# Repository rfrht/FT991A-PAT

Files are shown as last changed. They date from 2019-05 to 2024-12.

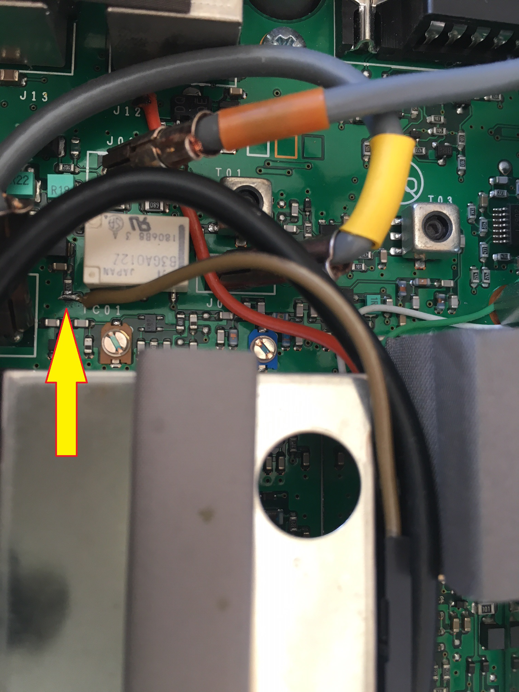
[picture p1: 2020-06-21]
Design/tx9.jpg

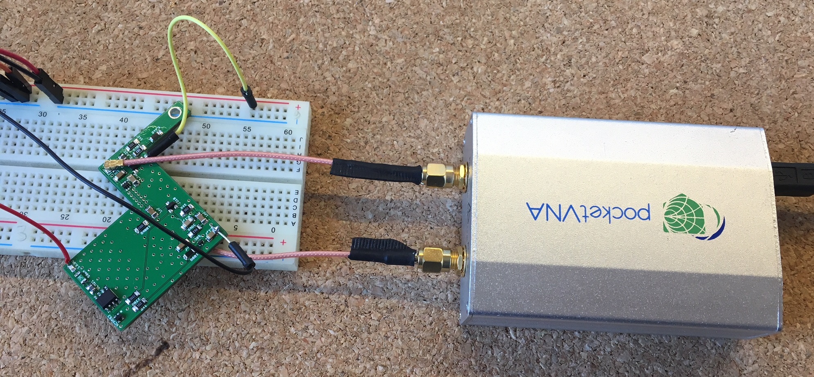
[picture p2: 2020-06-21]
Design/dut.jpg

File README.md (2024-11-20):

# Buffered IF tap board for Panadapter / SDR in a Yaesu FT-991-A

## Instructions, tests, pictures and full documentation: Check the [Wiki](https://github.com/rfrht/FT991A-PAT/wiki)

## Yaesu FT-991/A Custom Panoramic Adapter Buffered TAP Board for external SDR / Spectrum Analyser

This project is a remix of OE2DOR's [perfect and neatly crafted](https://raw.githubusercontent.com/Lightning1984/FT991A-PAT/PAT-Light/Design/FT991-PAT_Installed.jpg) FT-991/A Panadapter board with a high impedance IF tap, in order to disturb to a [minimum](https://youtu.be/yeTeMTJRBIg) the radio sensitivity.

This design is compatible with both A and non-A FT-991 transceivers.

The objective is to actually **lodge** a RTL-SDR **inside** a FT-991/A, with no extra cables coming off the radio.

The schematics are in Autodesk Eagle EDA format. Check the [Schematic](Schematic) folder. The [Design](Design) folder contains the ready to print Gerber files, images and some ancillary material.

The project genesis and some discussion are logged on QRZ Forum: [A FT-991/A IF tap for Panadapter / RTL-SDR inside the radio](https://forums.qrz.com/index.php?threads/hard-hack-embedding-a-sdr-in-ft-991a-need-rf-designers-review.650840/). If you need to ask questions, either file a Github Issue (preferred) or use the QRZ Forum.

If you are interested in build your own, [click here to download the Gerber](Design/board-gerbers.zip) and order in your favourite PCB Fab (like [JLCPCB](https://jlcpcb.com/quote), super cheap, good quality and $0 shipping on first order). **Ensure to read the [Wiki](https://github.com/rfrht/FT991A-PAT/wiki)**.

### Notes:

* The board (5 samples) costed $2 in [jlcpcb.com](https://jlcpcb.com/quote).
* The [parts](Design/bom-ft991-panadapter.csv) costs around $20 in Digi-Key.
* The IF signal is wide open, spanning the radio's [preselector filter range](/rfrht/FT991A-PAT/wiki/appendix-preselector-rx-stage-characteristics). With that comes also a problem: Very strong signals in passband might spew images through the spectrum in your SDR. Use the RTL-SDR RX gain to counteract.
* There's a Full Version with some extra bells and whistles (more details in the Wiki). Use the Branch "Rev-R-Full".

### Changelog:
Check [Here](CHANGELOG.md)

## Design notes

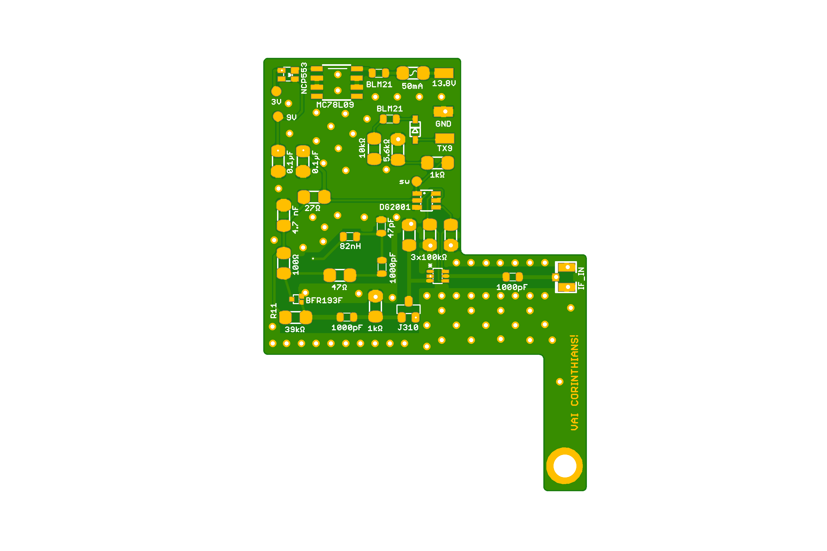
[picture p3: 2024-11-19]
Design/FT991-PAT_Bottom.png

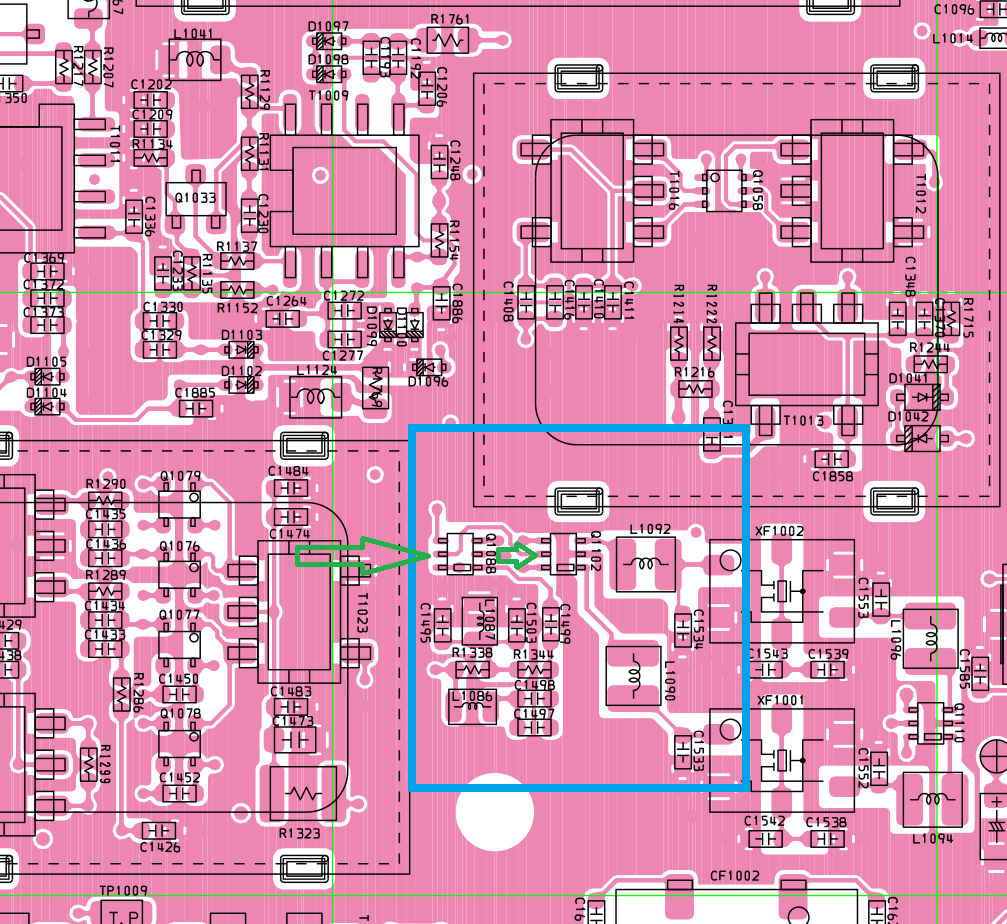
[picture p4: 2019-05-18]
Design/ft-991-tap-point.png

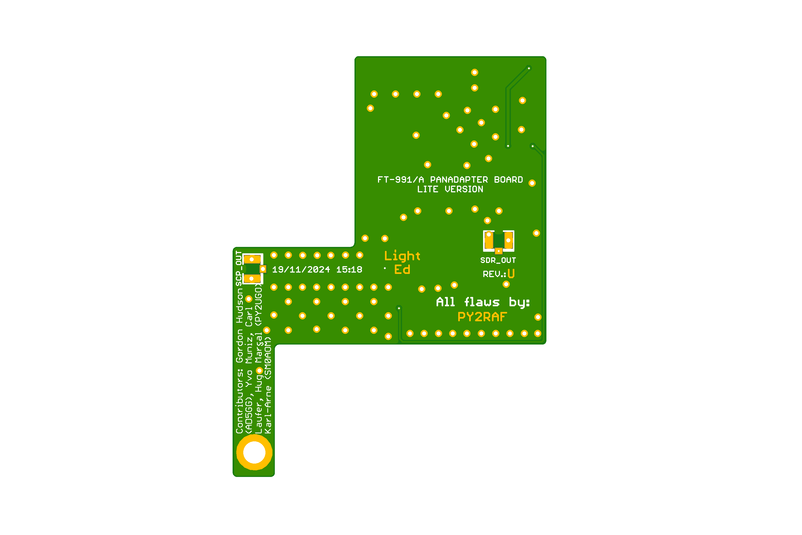
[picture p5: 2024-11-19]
Design/FT991-PAT_Top.png

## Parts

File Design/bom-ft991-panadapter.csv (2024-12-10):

Qty | Value | Parts | Digi-KeyPart
2 | 0.1µF | C2 C3 | 732-8109-1-ND
1 | 4700pF | C13 | 732-8119-1-ND
3 | 1000pF | C1 C11 C12 | 399-C0805C102J5GAC7800CT-ND
1 | 47pF | C14 | 712-QSCT251Q470G1GV001ECT-ND
3 | 100kR | R1 R5 R6 | CR1206-FX-1003ELFCT-ND
1 | 39kR | R11 | 118-CR1206-FX-3902ELFCT-ND
1 | 10kR | R3 | CR1206-FX-1002ELFCT-ND
1 | 5.6kR | R4 | 311-5.6KERCT-ND
2 | 1kR | R2 R7 | CR1206-FX-1001ELFCT-ND
1 | 100R | R12 | CR1206-FX-1000ELFCT-ND
1 | 47R | R13 | CR1206-FX-47R0ELFCT-ND
1 | 27R | R14 | CR1206-FX-27R0ELFCT-ND
1 | 82nH | L1 | 445-1034-1-ND
2 | BLM21 | L2 L3 | 541-2293-1-ND
1 | 50mA | F1 | 283-3132-1-ND
1 | 1SS355VM | D1 | 1SS355VMFHTE-17CT-ND
1 | PE4259 | Q1 | 1046-1011-1-ND
1 | MC78L09 | Q2 | MC78L09ABDR2GOSCT-ND
1 | DG2001 | Q3 | DG2001EDV-T1-GE3CT-ND
1 | NCP553 | Q5 | NCP553SQ30T1GOSCT-ND
1 | J310 | Q7 | MMBFJ310LT3GOSCT-ND
1 | BFR193F | Q8 | BFR193FH6327XTSA1CT-ND
3 | U.FL Port | X1 X2 X3 | A144746CT-ND
1 | U.FL IF Cable | J1 | WM9117-ND
1 | U.FL Panadapter to SDR Cable | J3 | 2057-CA-DKCA1-152L0-I0-12-ND
1 | USB2514BI | Q1012 | USB2514BI-AEZG-CT-ND

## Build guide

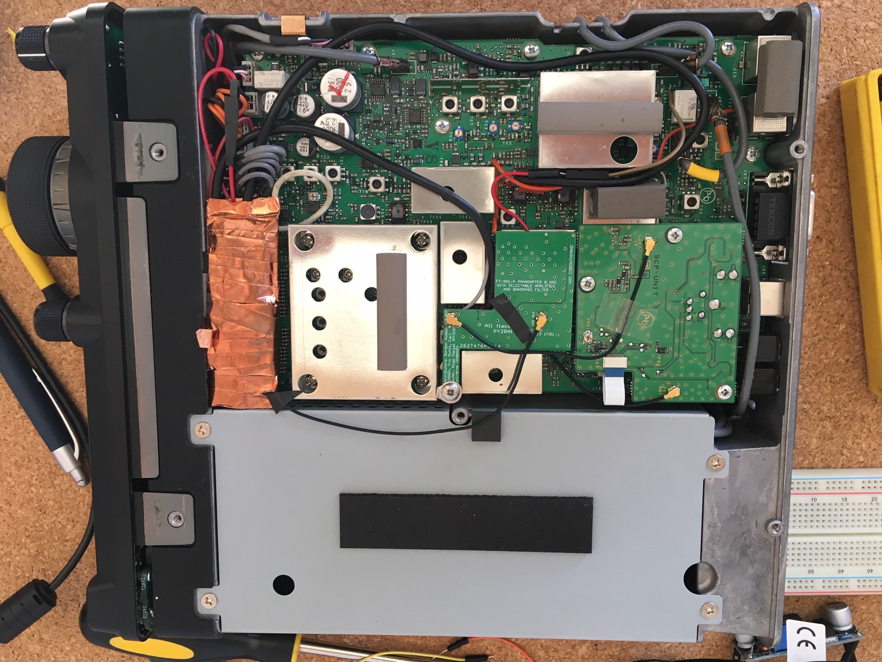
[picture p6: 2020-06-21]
Design/FT991-PAT_Installed.jpg

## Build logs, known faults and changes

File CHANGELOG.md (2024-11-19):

# Changelog

19/Nov/2024 - Revision U, Lite version
* Minor changes over Rev. T: Updated some component values, improved footprint for BFR193 (it's a **ROYAL PAIN IN THE ASS** to solder) and NCP553. Version is good enough to be promoted to Master branch.
* Resolves: [#20](https://github.com/rfrht/FT991A-PAT/issues/20), [#26](https://github.com/rfrht/FT991A-PAT/issues/26), [#27](https://github.com/rfrht/FT991A-PAT/issues/27)

28/May/2024 - Revision T, Lite version
* Fixed a gross flaw in Revision S: The RF switch was flipped out /o\  Resolves #25
* Updated BOM, renamed some capacitors and the matching network components are labeled as {C,R}1x
* There are more gain to be obtained from BFR193. Added a bias and matching network design from [Infineon's AN-1806](https://www.infineon.com/dgdl/Infineon-Design_Guide_for_low_noise_TR_in_FM_radio_FE-ApplicationNotes-v01_00-EN.pdf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). While the matching network isn't suitable for BFR193, the footprints will be good enough to test other components and values. Capacitors are 0805, Resistors are 1206.
* This revision is planned to be a testbed for a proper bias and match network in order to get better gain figures from BFR193.

11/Apr/2022 - Revision S, Full Version
* Replaced 2SC5086 with BFR193F amplifier, since 2SC5086 is now EOL
* Added a RF choke (L1) to avoid signal feedback propagating in 3V line
* New RF switch design - now uses an analog switch to flip the RF switch.
  While this added new parts (1 switch and two resistors) and extra
  complexity, this actuation format is industry-standard and allows
  for substitutes of PE4259 (which was unobtanium during the pandemics).

28/Jan/2022 - Revision R, Full & Lite
* Designed larger pads for the Diodes and NCP553

14/Apr/2021 - Revision R, Full & Lite
* Removed C6 - That's for DC blocking and no DC is present at this point
* Removed R6, R9 - J310 chain connected directly to +9V lines, 2SC5086 connected directly to 3V line.
* Cleared some lines away away from the PCB border, too close to PCB edge.

21/Feb/2021 - Revision Q, Full & Lite
* Better Silk-Screen Pin 1 markings for Power regulators
* Larger footprint for 2SC5086
* Moving 0.1µF transistor caps away from RF section
* Lots of re-routing
* Changing 1000 pF decoupling caps to _Low ESL_ type and 0805 footprint for better RF performance
* Took advantage of J310 [source & drain interchangeability](https://www.allaboutcircuits.com/textbook/semiconductors/chpt-5/transistor-switch-jfet/) and rerouted component for better placement and signal routing.
* Labeled a few signals in Eagle file for better understanding of signal route/path
* Changed two resistors in Amplifier stage for extra 0.3 dB gain - and updated BOM
* Added ground pad
* Larger ground exposed ground pad near at the screw
* Changed pad for RF components to a rounded layout
* Enlarged the RF wire signal, in order to reduce the internal signal impedance
* Improved component silk screen, for better component placement cue (and get rid of manual silk cues)
* Removed components from the board lid part, moved to larger board part

05/Jul/2020 - Revision P, Lite Version
* Repositioned the SDR Out port to right above the DC block cap
* Changed RF switch layout - now IF input uses the RF switch's `RFC` port instead of RF2 - The PE4259's `RF{N}` port gets in a grounded state instead of just reflecting out the data when the port is not selected/active. More details [here](https://github.com/rfrht/FT991A-PAT/wiki/appendix-pe4259-grounded-rf-port-when-port-is-not-selected)
* Got rid of the "Grounding" in RF1 port; that's not necessary because... Above
* Because of that... One less component (the 4.7 nF C2 cap)
* Few text corrections
* Added test pads for 9V, 3V and RF Switch
* A voltage line re-routed to the board edge, less ground plane disturbance

24/Nov/2019 - Lite Edition
* This revision features the bare minimum of the panadapter board: The TX signal RF switch and the Amplifier
* Greatly simplified and cheaper design
* More gain (due to less insertion loss of the RF switch chain that existed in previous revisions)

02/Nov/2019 - Revision O
* Board redesign
* Moved everything to the bottom side of the board, except for a RF switch and SDR/Scope unit ports
* Redesigned BPF (thanks to [SM0AOM](https://forums.qrz.com/index.php?threads/filter-design-help.671664/))
* Changed panadapter default state from disabled to enabled
* Changed RF front-end switch to use the TX9 signal instead of RX9
* Added a PTC fuse
* Choosed a simpler (and cheaper) 9V regulator

22/Jun/2019 - Revision N
* Removed the 5V regulator
* Removed the USB provisions
* Removed the G4HUP LPF. Reasoning: Found it of no use, since it cuts the signal 24 MHz above the IF center frequency. Replaced with a selectable 3-MHz wide 69.450 MHz BPF.
* Moved regulators to the top side of the board (to take advantage of heat dissipation)
* Moved the SDR Out port to the top of the board
* Added a large uncovered ground pad
* Tried to group the signals as much as possible and moved everything to the top of the board
* And thus, reduced significantly the BOM (35 to 25 different parts)

29/May/2019 - Revision M
EXPERIMENTAL.  In this revision:
* Got rid of the USB receptacle - Too much space in a tight radio
* Moved all GPIO pads to the upper board side
* Added a few missing Pin 1 references
* Renamed voltage regulators to somewhat shorter name
* Small re-routing - 9V regulator was entangled with capacitor

24/May/2019 - Revision L
EXPERIMENTAL.  In this revision:
* Added the ability to bypass entirely the amplifier and filters
  - Selectable by RF switch (default: off)
* Added a 3-pole Chebyshev Band-pass Filter centered at 69.450 MHz, 3 MHz
  wide
  - Selectable by RF switch (default: off)
* Revamped the Block Diagram
* Added the BPF LT-SPICE simulation
* Updated README, BOM, Gerbers and Pictures
* And yes, board is getting somewhat cluttered.

19/May/2019 - Revision K
* Changed footprints: BOM specifies 1206, project had 0805
  - Unified everything Resistors and Capacitors in 1206
  - Inductors are 0805
* A few routing enhancements
* Recalculated the component indexes
* Updated BOM to reflect the new component index
  - And also found a unaccounted resistor, whoops.
  - Reviewed the entire BOM and circuits. Now everything should be fine.

18/May/2019 - Revision J
* Changed SCPON signal to RX9
  - Added a Voltage Divider
* Changed the SMA-to-U.FL cable
* Added a few vias in large ground pads for voltage regulators
* Moved USB port a bit back in PCB

07/Apr/2019 - Revision I
* Created USB interconnection with the SDR
* Proper power management: Three voltage regulators in the board (9V, 5V, 3.3V)
* Power is only enabled with signaling coming from USB hub; otherwise, board quiesce
* Updated BOM

29/Mar/2019 - Revision H
* Revised routes in Cheb Filter - Made the tracks fatter and straighter
* Repositioned Q2 for better signal routing
* Better unit spelling in silk screen for resistors
* Flipped IF/SCP ports
* A few routing changes.

27/Mar/2019 - Revision G
* Removed a lingering DC blocker capacitor in filter in after RF switch.
* Added chokes in DC IN lines (3.3V and 5V) (yet another Gordon trick)

27/Mar/2019 - Revision F
* Added 1 nF capacitors in RF lines in PE4529 (except RF2, goes with a 470 pF to GND)
* Got rid of the VCC via which was crossing the RF line (argh)
* Finally got the courage to change a bit the board layout and escape from the thin strip that I was working previously.
* And another THANK YOU to Gordon AD5GG for his invaluable feedback

25/Mar/2019 - Revision E
* Changed the switch from a analog one (was a SN74LVC1G66) to a RF one (now: PE4259) (thanks to Gordon Hudson AD5GG)
* Now using 3.3V (because of PE4529)
* The switch default state now grounds the SDR
* Updated the list of contributors in PCB Silk Screen.

20/Mar/2019 - Revision D
* Moved to [OE2DOR](https://github.com/Lightning1984) **amazing** board design
* Added provision for two external inputs for latching control (actuating on a RF switch), isolating the SDR receiver when the two inputs are not in HIGH state. This is a bit of overkill in FT-991/A, but I want to be able to control the IF tap by software and be able to unplug it completely when not in use, without having to open the radio ;-)

### History (OE2DOR)

05/11/2018
 - Board Layout changed to fit neatly inside FT-991/A
 - Connection to IF using existing U.FL jumper cable 
 - Connection to FT991A SCP-UNIT using additional short U.FL jumper cable
 - Connection to SDR/SpectrumAnalyser using new U.FL to SMA cable
 - Mounting using M3/10mm PCB Spacer soldered to head of existing PCB mounting screw (since PCB mounting screw has no metric thread)
 - Fixation using M3 Plastic nut & screw sticking into tuning hole of shielding box
 - All but one resitor (1206) changed to 0805 to allow for smaller PCB layout

History (G4HUP/W3AXL)
Updated G4HUP / W3AXL panadapter tap
Simple revision to the G4HUP high-impedance IF tap with specific components and updated filters.

12/14/2017
 - Revised parts.md to add quantity of parts needed.

12/10/2017
 - Up and running on a Yaesu FT-991/A

12/10/2017
 - Revised component values to values that you can actually obtain. Added digikey parts list.

10/22/2017
 - Second revision testing complete and satisfactory. Up and running on a Yaesu FT-450D

08/30/2017
 - Schematic revised to fix capacitor placement error in original schematic. New boards sent out for fabrication and testing will be done when they get back.

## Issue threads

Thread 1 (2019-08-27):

Band-Pass Filter does not work.

rfrht, 2019-08-27:
**ISSUE**
As per [testing](https://github.com/rfrht/FT991A-PAT/wiki/testing) in Revision N, the selectable band-pass filter does not work - Matter of fact, it kills entirely the signal, from 1-900 MHz.

**ENVIRONMENT**
Revision N.

**RESOLUTION**
As of now this is not of super big concern, because the BPF is turned off by default.

Two possible resolutions;

1. Removing it entirely;
2. Implementing a good design.

rfrht, 2019-09-01:
Post at https://forums.qrz.com/index.php?threads/filter-design-help.671664/

rfrht, 2019-10-07:
Golden in aea2828dc01a8a442936111a30bc96a85ca1b191

_in vitro_ results in [QRZ Thread](https://forums.qrz.com/index.php?threads/filter-design-help.671664/page-2#post-5182107)

Pending build and verify _in vivo_.

rfrht, 2020-06-21:
Resolved@ Thanks to SM4AOM/Karl Arne.

Closed 2020-06-21.

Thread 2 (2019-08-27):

Remove the "Panadapter Enable"

rfrht, 2019-08-27:
**ISSUE**
The board only comes to life with a `PAT_ENABLE` signal. This requires a Voltage regulator with a Enable signal and extra wiring on the radio.

**BACKGROUND**
Originally, the project intended to also power the SDR dongle. However, I found that when feeding the SDR through the Panadapter board, the 9V regulator [gets real hot](https://forums.qrz.com/index.php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).
The radio is designed to run cold, as hot environment adds more noise to the sensible transistors/amplifiers in the RX stage. At this point, a selectable "Enable" made sense.
However, starting with Revision N, the SDR is powered by the +5V bus on the radio, straight from a 1.5A LDO which is properly attached to the aluminum chassis for proper heat dissipation.

**ENVIRONMENT**
All Revisions through N.

**RESOLUTION**
Use a smaller and cheaper 9V LDO.

As a workaround, wire directly the 13.8 `Vin` to the `PAT_ENABLE` pad.

rfrht, 2019-09-01:
Assigned, WIP.

rfrht, 2019-10-07:
Fixed in aea2828dc01a8a442936111a30bc96a85ca1b191

Closed 2019-10-07.

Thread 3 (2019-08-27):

Change first RF switch to "On by Default"

rfrht, 2019-08-27:
**ISSUE**
Currently, the panadapter does not tap the signal by default - It only opens to the signal upon the presence of both `RX_EN` **and** `RX_9` signals. Enabling a GPIO line to open the panadapter is just too clumsy, requires external software and is not friendly at all.

**ENVIRONMENT**
All revisions through N.

**BACKGROUND**
When projecting the board, it was unknown on how adversely would it affect the signal on the radio, thus I decided to keep it off by default. However, I found no signal degradation.

**RESOLUTION**
Change the Off by Default RF switch configuration to On by Default.
Change the logic AND IC to a "OR" IC
Change the radio signal tap from `RX9` to `TX9`.
Thus the switch will flip to ground the signal with either the presence of GPIO or `TX9`.

*Workaround*
Solder a 3V line to the `RX_EN` signal from the NCP553 regulator output.

rfrht, 2019-09-01:
Assigned, WIP.

rfrht, 2019-10-04:
OR IC: ‎SN74AHC1G32DCKR‎

rfrht, 2019-10-07:
Fixed in f93bf4a7a096de3da68612273629a3bb627728c1

Closed 2019-10-07.

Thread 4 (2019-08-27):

Add a protection fuse

rfrht, 2019-08-27:
**ISSUE**
Provide a fuse on the board for extra protection.

**ENVIRONMENT**
All revisions through N.

**BACKGROUND**
Currently, the Panadapter board sits behind a 3.5A fuse in the Main Unit. This is just too much.
The panadapter draws around 10 mA typical in the 13.8V line.

**RESOLUTION**
Implement a 20 mA PTC fuse.

rfrht, 2019-09-01:
Assigned, WIP.

rfrht, 2019-10-04:
Choose Bel Fuse ‎0ZCJ0005FF2E‎

rfrht, 2019-10-07:
Fixed in 9888a8bc56c6e88a80971f228149894bf89dd335

Closed 2019-10-07.

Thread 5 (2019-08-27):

Add Test Pads

rfrht, 2019-08-27:
**ISSUE**
Currently, the board sorely lacks a few test pads for testing and signal measurement.

**ENVIRONMENT**
All boards, through Revision N

**RESOLUTION**
Implement Test Pads in a few critical points.

rfrht, 2020-06-29:
To be addressed in Revision P

Closed 2020-07-05.

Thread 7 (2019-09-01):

Change 9V Voltage Regulator

rfrht, 2019-09-01:
The existing 9V regulator is just overkill - Change to something simpler.

rfrht, 2019-10-04:
Moved to MC78L09ABDR2GOSCT

rfrht, 2019-10-07:
Fixed in f93bf4a7a096de3da68612273629a3bb627728c1

Closed 2019-10-07.

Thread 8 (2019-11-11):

Fuse identified as 150 mA

rfrht, 2019-11-11:
It is a 50 mA :-P

rfrht, 2019-11-12:
Fixed by 9a267f2

Closed 2019-11-12.

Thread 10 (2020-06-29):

Input Signal attenuation when board is in TX9/Inhibit mode

rfrht, 2020-06-29:
During the Rev. O test, was found an unwanted input signal attenuation when the board is in TX9/Disable mode - The problem is thoroughly described in the [wiki article](https://github.com/rfrht/FT991A-PAT/wiki/appendix-pe4259-grounded-rf-port-when-port-is-not-selected)

The board **must not** cause any significant input signal attenuation, especially when in TX9/Disable mode.

rfrht, 2020-06-29:
Slated for resolution on Revision P.

Closed 2020-07-05.

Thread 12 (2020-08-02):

Stashed enhancements for Rev. Q

rfrht, 2020-08-02:
* Better Silk-Screen Pin 1 markings for Power regulators
* Larger footprint for 2SC5086
* Moving 0.1µF transistor caps away from RF section
* Lots of re-routing
* Changing 1 nF caps to Low ESL type and 0805 footprint for better RF performance
* Labeled a few signals in Eagle file for better understanding of signal route/path

rfrht, 2020-10-04:
Repositioning J310 JFET in order to avoid the Vin line crossing the signal lead

rfrht, 2020-10-10:
Currently examining the quantity of resistors and attenuation. Something to be tested with Revision P and if something noteworthy is found, implement in Revision Q.

wgxdz, 2020-10-11:
The part **MMBFJ310CT-ND** is marked as an obsolete item on Digi-key.

There are three suggested substitutes: **MMBFJ310LT1G**, **MMBFU310LT1G**, and **MMBFJ310LT3G**.

The footprint looks same. Could you take a look which one will be a good direct replacement?

rfrht, 2020-10-11:
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

Thank you *very* much for pointing! I have updated the BOMs to the new J310 part!

I appreciate a lot your review and feedback!

Will now create a new issue for the Attenuation and resistor tests. My VNA & oscilloscope aren't readily available here; and will file a new issue for the tests.

rfrht, 2020-10-11:
> Currently examining the quantity of resistors and attenuation. Something to be tested with Revision P and if something noteworthy is found, implement in Revision Q.

Tracking in #14

rfrht, 2020-10-22:
- Added a Ground Pad
- Slight change in resistors for a slight gain (0.3 dB) in amplification (see #14)

Closed 2021-04-13.

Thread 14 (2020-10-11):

Review resistors and attenuation in RF lines

rfrht, 2020-10-11:
Resistors R5, R7 and R10 are essentially attenuators in RF lines - this was blindly copied from the original G4HUP project, with no test of what's the effect in gain output.

As per [G4HUP statement](http://icas.to/PAT/PAT%20V2%20description.pdf) in his project description:

    [...]and a resistive attenuator to allow the overall gain of the board to be matched to the input requirements of the SDR.

Will test in a VNA what's the effect of these transistors, especially the R5 which can cause an attenuation in the input signal.

rfrht, 2020-10-22:
# TL;DR:
The resistors are indeed needed.

# Long-winded
The resistors are crucial for matching the loads and ensuring the best performance of the amplifiers. I experimented in an speculative/exploratory by entirely removing and changing the values with the resistors that I had around. Findings:

* The first `R5` 100K resistor ensures signal stability.
* The `R7` resistor already provides the best performance at 1K
* `R8` and `R10` had their values changed slightly; `R8` changed from 39K to 10K, `R10` from 100R to 220R.

That yielded a modest 0.3 dB gain increase.

# Original component values result
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

# New component values result
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

rfrht, 2020-10-22:
Included in c3bcb1ba.

Closed 2020-10-22.

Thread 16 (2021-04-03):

Where to tap TX9 on FT991 non-A?

ianfromnyc, 2021-04-03:
Looking at https://github.com/rfrht/FT991A-PAT/wiki/installation#tx9 and comparing the image to my 991 non-A, it appears that the highlighted section is not present on my radio.  Might it be possible to point me toward an alternate location to tap the TX9?

Here's an photo from the same section on my radio, in case I'm just not seeing it.
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

Thanks

rfrht, 2021-04-03:
Hello there, Ian!

First of all - **thank you very much** for reporting this issue.

You are right, this component is non-existent in FT-991.

**However**, while finding for a suitable place I found an even better place to tap the signal from - it is the collector (the lid) of Q1061. Larger component, and bonus point - common to both FT-991 and FT-991A.

Schematic:
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

Board:
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

Can I ask you a favour? Can you please take a picture of this point so I can use your picture in the Wiki?

Your previous picture looks gorgeous and I'd appreciate a lot if you could provide the picture of the actual board - and provide the credits of course.

Thank you very much for reporting!

ianfromnyc, 2021-04-03:
Hi Rodrigo,

Thank you for replying so quickly!  Here are the photos you asked for.

Q1061 is underneath what I believe is the PLL module and a RF shield.

First, remove the 4 screws at the corners of the shield:

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

Next, remove the PLL module.  It is only attached by the pin headers at the left and the top:

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

Now you can access Q1061:

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

One more question: it looks like I'll need a standoff to mount the panadapter using the mainboard mounting screw.  Do you know what size the screw is?  Alternatively, is there another way to ground the panadapter without screwing it down?

Thanks

Ian P

rfrht, 2021-04-04:
Oooh no no no **stop right now Ian**

rfrht, 2021-04-04:
This is bad news all way long man, i didn't know it was underneath the PLL Unit, damn! Don't tap from there!

There are two resistors in this side of the board (the other TX9 line elements are underneath the Main unit and we don't want that)

Give me a few minutes more and and I'll provide you the two other options - then you can find out what's the better option

And will reply the other questions too. Stand by!

ianfromnyc, 2021-04-04:
Okay, I've already soldered the wire to that transistor, but I can move it somewhere else.  Out of curiosity, what makes that such a bad spot?

Regarding the mounting screw, I had a look at the upstream repo and it seems OE2DOR soldered a M3 standoff to the screw then mounted the panadapter to that.  I'll try that unless you have a better suggestion.

rfrht, 2021-04-04:
Ok Ian

Besides Q1061 we have the following components in TX9 line, namely:

* R1429
* R1601
* R1625
* R1754
* R1755
* R1759

TL;DR: Only R1601 and R1625 are suitable, because they are on the upper side of the board. All other compoonents are underneath.

R1429:
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

R1601 and R1625:
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

* R1754, R1755 and R1759:
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

Now let me get the location for 1601 and 1625.

rfrht, 2021-04-04:
> Okay, I've already soldered the wire to that transistor, but I can move it somewhere else. Out of curiosity, what makes that such a bad spot?
Man, I am sorry - I did not know really that there was a board above that spot, Ian.

The reason this is a bad spot, well the problem number zero is the shield - The shield presence means it has to be a very controlled in terms of noise.

The wire traveling from the SDR can become an unintentional radiator *right below* the PLL Unit risking wreak havoc in your frequency stability - and we don't want that.

> Regarding the mounting screw, I had a look at the upstream repo and it seems OE2DOR soldered a M3 standoff to the screw then mounted the panadapter to that. I'll try that unless you have a better suggestion.

In my case, I worked with what I had, Ian - and that was not exactly pretty.

I used those VGA nuts and 'forced' it a bit on the screw slot. I didn't have anything that would be that tall and would be a perfect fit :-(

Thus, the VGA nut.

ianfromnyc, 2021-04-04:
Thanks for the warning, I'm thinking R1625 is the better choice since it's closer.  Though, it is right next to (but still outside the shield of) the PLL unit, so maybe not?

What do you think?

rfrht, 2021-04-04:
So here is the PCB location, Ian.

R1625
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

R1601
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

**Fun fact**: Both are common to 991A too :-P

I think that the R1601 would be a better idea, in a less cluttered part of the PCB board - and at that point it controls the TX GND signal to Linear Amplifier, *far far away* from R1625, which is nearby the critical signal path.

Now it is your call - I don't know what are the obstacles or challenges for 1601.

Let me know your conclusion?

And apologies again for your excursion underneath PLL unit, ugh.

ianfromnyc, 2021-04-04:
Thank you very much for the advice.  I'm a novice so I really appreciate it.

I'll try the R1601 and let you know how it goes.  I'll also make sure to get some nice pictures for the Wiki.  I may not get to it until Tuesday because of the holiday, though.

rfrht, 2021-04-04:
Take your time - and I wish you and your family a happy Easter!

Thanks Ian, that was fun (other than still baffled about the PLL Unit)

ianfromnyc, 2021-04-08:
Hi Rodrigo,

I got the board installed and the panadapter appears to be working, thanks again for all the hard work!  Here's a photo of the TX9 wire soldered on to R1601:

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

Unfortunately, I must have damaged the FT-991 during the installation because now the radio is deaf on HF.  144 and 430 still work.  I think it might be something to do with how I soldered the IF output to Q1088 or Q1102, which I had to try a few times before I got a good connection.  If I had damaged either of those switches, would it deafen the radio on HF but not V/U?  In any case, this is totally my fault.

I wish I had better news but I do appreciate all the work that went into this project and all your guidance on finding the TX9.

Thanks again

Ian P

rfrht, 2021-04-08:
Oooooh boy Ian man I'm so sorry to hear man

Did you reconnect firmly the coax that you removed to solder the TX9?

>  If I had damaged either of those switches, would it deafen the radio on HF but not V/U?

Okay look at the below annotated schematic:

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

If a switch is damaged, it ought to be Q1088. Q1102 selects the roofing filter, and if you get into defect over there, you would get signal problems when switching between SSB, that uses 3K filter and FM, that uses the 16K filter.

Matter of fact, change modes in HF, to FM for example, if you can get some signal. IF it is the case, then damage is in Q1102.

The good thing is these switches are readily available, the sad part is DigiKey has no stock

https://www.digikey.com/en/products/detail/psemi/4259-63/2614473

However, if you built your panadapter, smile: It is the very same RF switch that I used in the board design.

ianfromnyc, 2021-04-08:
Thanks again for the very detailed analysis. I've ordered the switches anyway, just in case I decide to try replacing them.  I have a few weeks of backorder lead time during which to think it over.

rfrht, 2021-04-08:
Feel free to get in touch here or by e-mail. QRZ me and email is over there.

Closed 2021-04-08.

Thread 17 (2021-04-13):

Test results from Revision R

rfrht, 2021-04-13:
Revision R Lite/Full just went published.

Need to:

1. Procure the 0805 capacitors
2. Procure the boards
3. Test the new board
4. If results are sound, update the Wiki Testing section and Promote Rev. R to Master

rfrht, 2021-04-13:
Note to self: Add a note about 0.6 mm PCB thickness

rfrht, 2021-10-03:
Board a parts procured; pending delivery

rfrht, 2022-01-01:
Boards delivered, components were lost in snail mail. Bought the components again.

rfrht, 2022-01-28:
https://github.com/rfrht/FT991A-PAT/wiki/testing

Closed 2022-01-28.

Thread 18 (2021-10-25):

USB replacement wiki

Kermitdk, 2021-10-25:
Hi
It look like there are images missing in  the description regarding replacing the main USB controller.

br
Claus

Manawyrm, 2022-01-01:
Hi,

@rfrht
> pending receive the Revision R board

Any recommendations whether I should order the Revision R or the current Revision Q?
I'm not afraid of a little SMD rework or modding, just mainly wanted to know how big the difference is and if it's worth the "risk" of ordering the new one.

Thanks!

rfrht, 2022-01-01:
> Any recommendations whether I should order the Revision R or the current Revision Q?

Hello, Tobias!

Go for Rev. R! The [Changelog](https://github.com/rfrht/FT991A-PAT/blob/Rev-R-Full/CHANGELOG.md) is far from being risky. The 2SC5086 and J310 were fed by resistive drops - Just got rid of them and is now making use of the existing power lines.

I procured the components in September, and it just didn't get delivered here in Brazil. Bought it again a couple of days ago, delivered to a Brazilian friend in NYC (PY2UGO) and will have the parts by the second half of January, when friend gets back to Brazil.

Then will post the test results and make Rev. R the current one.

Feel free to reach if you have any questions!

rfrht, 2022-01-01:
> It will be back (hopefully) in a month from now!

Will tentatively bring back my home server this Sunday - fingers crossed!

Manawyrm, 2022-01-01:
Awesome, thank you for the quick response!
I'll go buy some parts then :)

Happy new year,
Tobias

rfrht, 2022-01-03:
> Hi It look like there are images missing in the description regarding replacing the main USB controller.
>
> br Claus

Hello @Kermitdk @Manawyrm

**Finally** I got my home server back, after long 5 months! The images are now rendering correctly.

Closed 2022-01-03.

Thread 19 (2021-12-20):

Error in Wiki: SHIFT Menu Item Description

4andy2001, 2021-12-20:
In the SHIFT menu item description, RX or TX field (see below), it should say RX, not TX:

SHIFT

    WHAT: The shift function "shifts" (doh again) your receiving bandpass to above or below (or left or right), removing either the bass or treble part of the signal depending to the direction that you set the shift - narrowing the received signal.
    AVAILABLE OPTIONS: -1200 Hz to +1200 Hz. 0 means no shift, disabled. Set with "Multi" encoder.
    **_RX or TX? TX_**
    WHICH MODE? AM, SSB, CW
    WHEN TO USE: The primary use is to defend from an adjacent signal over the lower or higher edge of your receiving signal. Use shift to dodge this interfering signal.
    CAVEAT: This is also useful to make the receiving less tiring, irrespective of having or not an interfering signal - Try using Shift between -600 and -200 together with DNR - I promise you will love it!

4andy2001, 2021-12-20:
My pleasure.

Found your wiki very helpful bringing up digital modes on my rig-appreciate the effort you put into it.

Happy holidays!

Closed 2021-12-20.

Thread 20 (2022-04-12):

2SC5086 is now EOLed

rfrht, 2022-04-12:
As per Digi-Key announcement:

| Manufacturer | TOSHIBA SEMICONDUCTOR AND STORAGE (VA) |
| :---: | :---: |
| Description | RF TRANS NPN 12V 7GHZ SSM |
| Manufacturer Part Number | 2SC5086-O,LF |
| Digi-Key Part Number | 2SC5086-OLFCT-ND |
| Status | End Of Life |
| Last Time Buy Date | 06/30/2022 |

rfrht, 2022-04-12:
Prepared Revision [Revision S](/rfrht/FT991A-PAT/tree/Rev-S-Lite) replacing 2SC5086 with BFR193F

Pending:
- Order board
- Order components
- Test

rfrht, 2022-04-12:
Note to self:

[RF choke performance](https://ds.yuden.co.jp/TYCOMPAS/ut/detail?pn=LSQMB201616T3R9J&u=M)

rfrht, 2023-11-21:
Rationale behind BFR193:

https://www.reddit.com/r/rfelectronics/comments/yzsyzt/help_choosing_a_transistor/

Closed 2024-11-19.

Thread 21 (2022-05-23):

FT991A-PAT components are unobtanium due to supply chain madness

amjoseph-nixpkgs, 2022-05-23:
Hi, thank you (and W3AXL, and OE2DOR) for designing this awesome board and sharing it with us!

I've ordered my PCBs from OSHPark, but discovered that five of the components on the BOM are not available, due to general supply chain insanity (which has been going on for a couple of years now...).

I went ahead and ordered from Digikey anyways, with the following four replacements; do you think these choices will work?  If not, can you suggest better substitutions?

* [MC78L09ABDR2GOSCT-ND](https://www.digikey.com/en/products/detail/onsemi/MC78L09ABDR2G/1481351) -> [296-11126-5-ND](https://www.digikey.com/en/products/detail/texas-instruments/UA78L09ACD/382182)
* [NCP553SQ30T1GOSCT-ND](https://www.digikey.com/en/products/detail/onsemi/NCP553SQ30T1G/920092) -> [1662-1980-1-ND](https://www.digikey.com/en/products/detail/ablic-inc/S-817A30ANB-CUTT2U/6120535)
* [MMBFJ310LT1GOSCT-ND](https://www.digikey.com/en/products/detail/onsemi/MMBFJ310LT1G/919591) -> [MMBFJ211CT-ND](https://www.digikey.com/en/products/detail/onsemi/MMBFJ211/1049196)
* [2SC5086-OLFCT-ND](https://www.digikey.com/en/products/detail/toshiba-semiconductor-and-storage/2SC5086-O-LF/4516268) -> [BFR106E6327HTSA1CT-ND](https://www.digikey.com/en/products/detail/infineon-technologies/BFR106E6327HTSA1/1281529)

The real problem, however, is [USB2514BI-AEZG-CT-ND](https://www.digikey.com/en/products/detail/microchip-technology/USB2514BI-AEZG-TR/3873166). That is total unobtanium right now, Digikey is showing an 18-month lead time.  And it isn't a commodity part.  Any ideas about what to do here?  Should I try buying an old USB hub on eBay and scavenging from it?  Any ideas which high-volume products might have used this IC?

Thanks again,

rfrht, 2022-05-24:
Hello there, Joseph - and thanks for getting in touch!

Man, I've been for the last two hours drowning in datasheets and here's what I've found.

* The 9V regulator (MC78) is still stocked, so I didn't evaluate the substitute.
* The 3.3V regulator (NCP553) replacement (S-817) looks good. But the price, ugh...
* The J310 I was able to find a even better mach. Replace with the U310; Digikey [MMBFU310LT1GOSCT-ND](https://www.digikey.com/en/products/detail/onsemi/mmbfu310lt1g/919592).
* Now, the 2SC5086... Argh. We have few problems. First, the package is proprietary. The BFR106 that you pointed looks okay in its specs, but the footprint won't match the 2SC5086 in the board (the BFR106 is a SOT-23).

I am preparing Revision S replacing the 2SC5086 with a [BFR193](https://www.digikey.com/en/products/detail/infineon-technologies/BFR193FH6327XTSA1/2337789), but I am not entirely convinced about that part. Anyways; I have ordered the BFR193 and will made its trip to here in some more weeks. Ah, the BFR193 is *also* not compatible with the 2SC5086 footprint.

Matter of fact, I was thinking about selecting other component; capping a good lot the Ft (frequency transition), because we are in need of a product which usage is in the **low** VHF frequency, ~70 MHz. Using so low frequencies with products meant to use in higher frequencies is not a great idea. And the bias will probably need some attention.

After these two hours fiddling with datasheets, availability, etc., I was flirting with an Infineon [BGA614](https://www.digikey.com/en/products/detail/infineon-technologies/BGA614H6327XTSA1/2337815), but man... Lots of testing would have to be done, redo the bias network etc.

So tl;dr: As of now, it is... Complicated.

The USB2514, phew... last time I bought it was in 2020. I had a spare one and resold to a friend who bought the panadapter board from me.

Ah; you missed the PE4259 (I **strongly** recommend the RF switch to take the panadapter out when transmitting, it causes some shenanigans when transmitting) - that was pretty much unobtanium too. Fortunately I do have some here, and if you found where to buy let me know, in case someone ask.

Let me know if you have any further comments. Thanks for stopping by! o/

rfrht, 2022-05-24:
Note to self: The BFR193F was chosen because it is listed as a 2SC5086 replacement in [Infineon's RF Dsicretes Selection Guide](https://rf3.org:8443/q/infineon-rf.pdf)

a-m-joseph, 2022-05-24:
> The USB2514, phew... last time I bought it was in 2020. I had a spare one and resold to a friend who bought the panadapter board from me.

Ugh, not what I was hoping to hear :(

Microchip just published a production change notice indicating that they have added a second IC packaging provider for the product, so presumably production has resumed, but that certainly hasn't been reflected in the lead times.

Looks like there are a few grey-market sources on ebay, at least one of which looks not-completely-shady, so I will roll the dice on that one.

> The 9V regulator (MC78) is still stocked, so I didn't evaluate the substitute.

Oh wow, they must've just gotten a shipment.  Sweet.

> * First, the package is proprietary

WTF?  Why, oh why, must manufacturers do things like this...

> Matter of fact, I was thinking about selecting other component; capping a good lot the Ft (frequency transition)

Thank you so much for looking at this!  My analog experience is limited to VLSI and I have zero experience with RF design on any level, so I really appreciate it.

> Ah; you missed the PE4259

You're right.  I substituted [PE42421SCAA-Z](https://www.digikey.com/en/products/detail/psemi/PE42421SCAA-Z/3728588); do you see any problems there?  I felt a bit safer with that substitution since the gate on that switch is a (very) low-frequency signal.

I'm closing this (thanks again for your response!) but will follow up with a report on how things turn out.

rfrht, 2022-05-24:
*Reopening it and leaving it open as it contains useful information to the wider audience - added reference in Readme.*

Hello again Joseph!

Definitely, the [PE42421](https://www.digikey.com/en/products/detail/psemi/PE42421SCAA-Z/3728588) is **not** a suitable candidate. It's exactly the same part as PE4259, **except** that the RF control flips the RF1/RF2 ports the other way. Ah and it is not stocked at DigiKey too.

I was evaluating the Skyworks [SKYA21001](https://www.skyworksinc.com/-/media/SkyWorks/Documents/Products/1901-2000/SKYA21001_202936H.pdf) or [AS213-92](https://www.skyworksinc.com/-/media/SkyWorks/Documents/Products/1-100/200193D.pdf) - but the RF switch works differently from the 4259; it is controlled by powering **either** RFC or VCC. Perfect pinout match, but the logic doesn't work.

rfrht, 2022-05-24:
Update.

I have checked all [RF switches, in stock, SPDT, SC-70 package](https://www.digikey.com/en/products/filter/rf-switches/865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), and **none** are directly compatible with PE4529, the way it was implemented in the panadapter board:

The PE4259 supports two switching modes:

* Vcc always high & RFC high/low (the design choice)
* **Either** VCC or RFC high

Welp, seems that the *either* VCC or RFC mode is the standard/de facto, as **every product** supports it, with only the PE4259 allowing the VCC + RFC state mode.

This design make sense in the panadapter, as it would require another component to drive it accordingly, but... Well, makes it hard (impossible?) to find replacements.

rfrht, 2022-05-24:
USB2514BI [Microchip.com store](https://www.microchip.com/en-us/product/USB2514B#buy-from-store): Ships on May, 2023

😐

a-m-joseph, 2022-05-25:
> I have checked all [RF switches, in stock, SPDT, SC-70 package](https://www.digikey.com/en/products/filter/rf-switches/865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), and **none** are directly compatible with PE4259, the way it was implemented in the panadapter board:

I guess I should wait for the next revision of the board.

rfrht, 2022-07-19:
Hello @amjoseph-nixpkgs

Just pushed a commit that might address this issue. It's on [Revision S Lite](https://github.com/rfrht/FT991A-PAT/tree/Rev-S-Lite) tree

In this revision I am using the "compatibility" way to flip the PE4259, which would essentially allow to replace it by any other RF switch with compatible component footprint.

amjoseph-nixpkgs, 2022-07-19:
Boards+stencil ordered from OSHPark; will let you know when it arrives and I build it.

I did in fact manage to get my hands on 10pcs of the unobtanium USB chip from an extremely unofficial distributor.  If you want the leftovers (8-9pcs probably) I'd be happy to mail them to you (once I verify that I didn't get swindled into buying a bunch of empty QFN packages!)

> In this revision I am using the "compatibility" way to flip the PE4259, which would essentially allow to replace it by any other RF switch with compatible component footprint.

Is there a specific replacement part you can recommend at this time?

rfrht, 2022-07-19:
> Boards+stencil ordered from OSHPark; will let you know when it arrives and I build it.
Hooray!!

> I did in fact manage to get my hands on 10pcs of the unobtanium USB chip from an extremely unofficial distributor. If you want the leftovers (8-9pcs probably) I'd be happy to mail them to you (once I verify that I didn't get swindled into buying a bunch of empty QFN packages!)
That was... Bold! Good luck!

> Is there a specific replacement part you can recommend at this time?
Ah, supply chain. Well, there's a pSemi part with slightly lower specs (though better than Skyworks) and reasonable pricing: [PE42421SCAA-Z](https://www.digikey.com/en/products/detail/psemi/PE42421SCAA-Z/3728588).

Fun fact: The RF switch logic follows the same as PE4259 and is a *direct replacement* part. It's just the specs that are a bit (very small bit) degraded.

rfrht, 2023-11-16:
Very well. After more than a year, I finally moved, inventoried my parts, will test the new revision board (S) and I was able to - other than the 2SC5086 EOLed part - order everything.

Closing this issue.

Closed 2023-11-16.

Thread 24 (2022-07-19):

Revision S: Assemble and test the new board

rfrht, 2022-07-19:

rfrht, 2023-11-21:
Resolved #22 and #23. Pending delivery, so the tests can (finally) be done.

rfrht, 2024-02-21:
Board is now assembled, pending tests.

rfrht, 2024-05-28:
Board was shit. Results in #25 .

Closed 2024-05-28.

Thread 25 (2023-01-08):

Gain very bad

F4HZA, 2023-01-08:
hello,

Thank you for this project, great work, I like the integration in the FT-991A.
I realized the S revision with the BRF193F, but I have a gain problem.
The gain is around -20db, I changed the BFR193F but the same.

I tested in the FT-991A but the attenuation is too high with IPO or AMP1 the signals are almost invisible with AMP2 I see the signals.

Do you have an idea of my problem? Is the new BFR193F transistor not suitable?

Thanks.
73.

rfrht, 2023-01-10:
Hello @F4HZA  o/

I have not tested the Revision S yet - this is the reason that I didn't promote it to the Main branch.

After consulting my digikey and JLCPCB orders, I found that I ordered the parts but never ordered the board - last known good revision is R.

When I get back to São Paulo (I'm in holidays here) I'll check my parts inventory and if all is sound, order a new board revision.

Side note, I found that this BFR193F is... **tiny**. Will be a pain to solder it; the 2SC5086 was already a challenge.

You might also want to check [this reddit thread](https://www.reddit.com/r/rfelectronics/comments/yzsyzt/help_choosing_a_transistor/) where I was suspecting that the BFR193F wasn't a suitable choice (spoiler alert: it seems it was the right choice).

Expect to have the Rev. S tested by mid March. Will keep this issue open for the time being.

rfrht, 2023-11-21:
Hello there @F4HZA !

Stopping by to let you know that I ordered the parts and the board this weekend - and will probably have all the ducks lined for testing in January!

rfrht, 2023-11-22:
Hello, Frederic!
Thanks for sharing the SPF5043Z, I checked its datasheet - and the automatic bias control is definitely a relief.

I built a board design that allows for a SPF5043 for testing, will put that on my future tests. Thank you **very** much for sharing!

So- how's your board working? Do you have any pictures to share?

F4HZA, 2023-11-23:
Hi,
I didn't take a photo of the mounted card, here is the image of the PCB.
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

I did it the old fashioned way, copper plate and iron perchloride. The components are quite large and soldering is easy.
I have attached the EAGLE project.
[Panadapter EAGLE with SPF5043Z - F4HZA .zip](https://github.com/rfrht/FT991A-PAT/files/13447043/Panadapter.EAGLE.with.SPF5043Z.-.F4HZA.zip)
 The card works perfectly, it was installed in January 2023 I have not reopened the FT-991A since. I use it with the SDRPLAY PRO2.

A point to review would be the 78L05 which heats up a little. Certainly also the adaptation of the values of the components I do not have the equipment to analyze. Make a professional PCB and resize it for good integration.
I had some problems correctly configuring the SDR CONSOLE software with the "External RADIO" and IF OUTPUT .
73. FAHZA.

rfrht, 2024-02-21:
Hey there @F4HZA !

I finally built the test board, based on the experimental Revision S. Two major problems:

1. The RF switch is flipped :-P It is decoupled by default - and this is the wrong logic. I have to fix that.
2. I found more or less what you found. While the loss wasn't that much you found, it is a non-neglectible -7 dB.

I ran a VNA sweep from 10-1000 MHz and found that the board performs reasonably well around 200ish MHz - wich makes me believe that the BFR193 is under heavy impedance mismatch at ~ 70 MHz (the S21 Marker 1).

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

I'll do some experiences here, and keep this issue open for the time being. I would like to thank you **very much** for the initial test and for reporting this issue!

rfrht, 2024-05-28:
Resolved by: [a6511e5](https://github.com/rfrht/FT991A-PAT/commit/a6511e5774d408b1fea3d411978e9201cb7058e5)

Closed 2024-05-28.

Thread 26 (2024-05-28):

Test Revision T board

rfrht, 2024-05-28:
Procure board, components and assemble it

rfrht, 2024-11-19:
All great. Check the [Testing](https://github.com/rfrht/FT991A-PAT/wiki/testing) section from Wiki.

Closed 2024-11-19.

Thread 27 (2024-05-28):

Improve BFR193 gain figures

rfrht, 2024-05-28:
There's a clear mismatch in BFR193 (see #25) which is hindering its full possible power.
Research a matching network (via trial and error) that can obtain a proper gain figure from this transistor.

rfrht, 2024-11-19:
WIN - Revision T plus matched network did **miracles**
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

rfrht, 2024-11-19:
All good - implemented as per [Infineon's AN-1806](https://www.infineon.com/dgdl/Infineon-Design_Guide_for_low_noise_TR_in_FM_radio_FE-ApplicationNotes-v01_00-EN.pdf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).

Closed 2024-11-19.

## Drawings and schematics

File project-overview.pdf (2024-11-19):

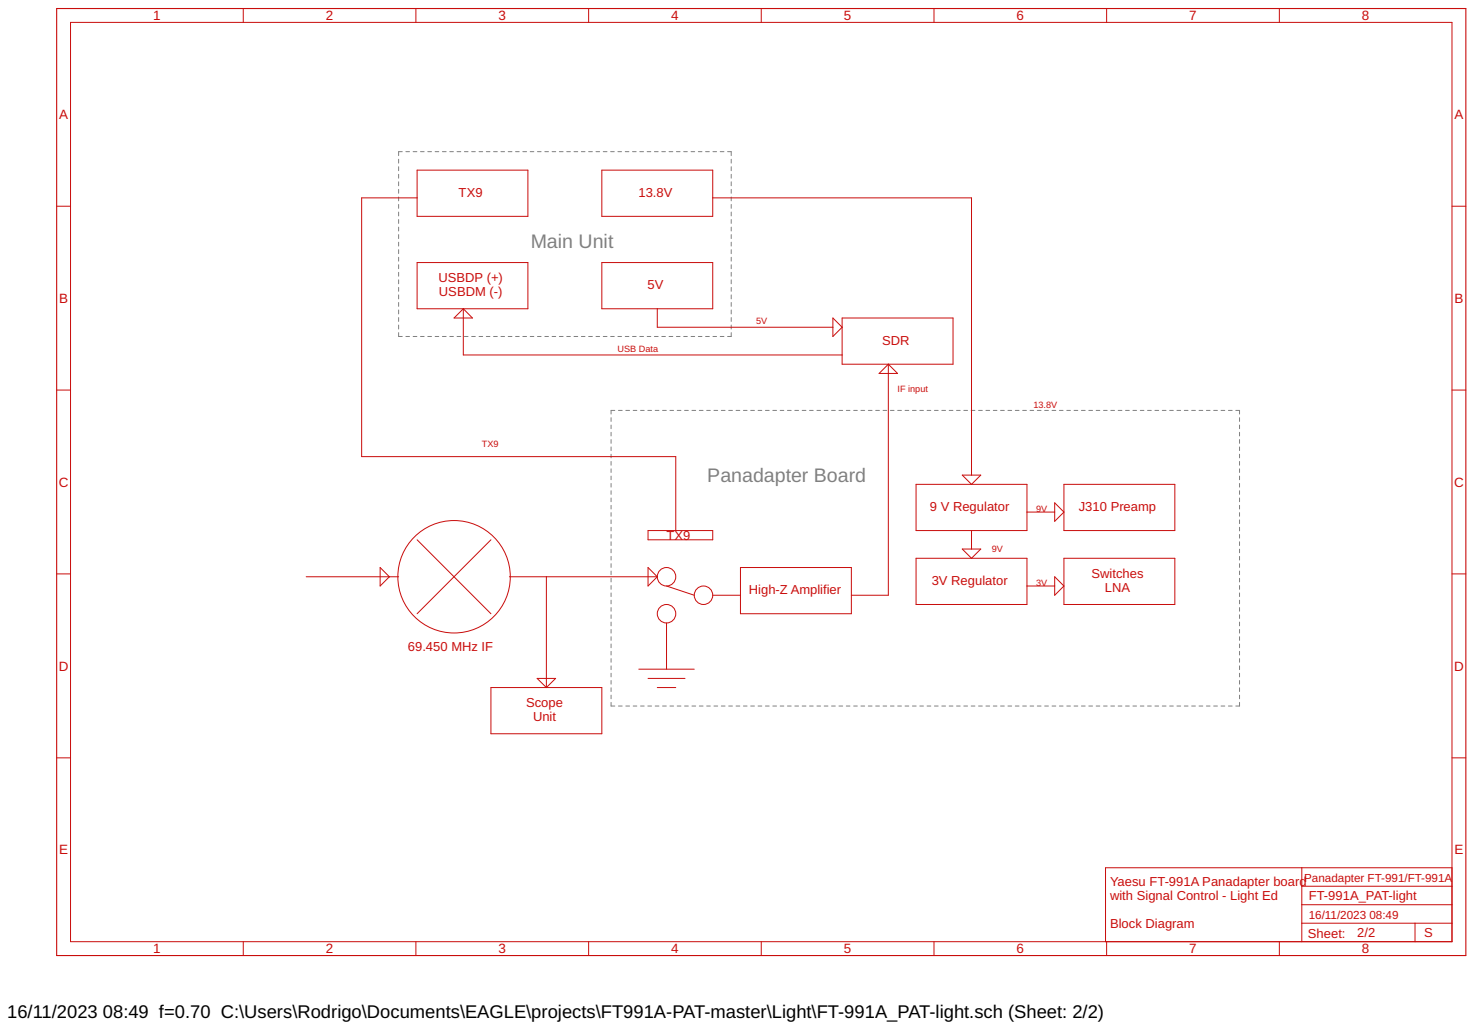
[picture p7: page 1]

Block Diagram | Panadapter FT-991/FT-991A Yaesu FT-991A Panadapter board with Signal Control - Light Ed

Sheet: 2/2 | S

16/11/2023 08:49 f=0.70 C:\Users\Rodrigo\Documents\EAGLE\projects\FT991A-PAT-master\Light\FT-991A_PAT-light.sch (Sheet: 2/2)

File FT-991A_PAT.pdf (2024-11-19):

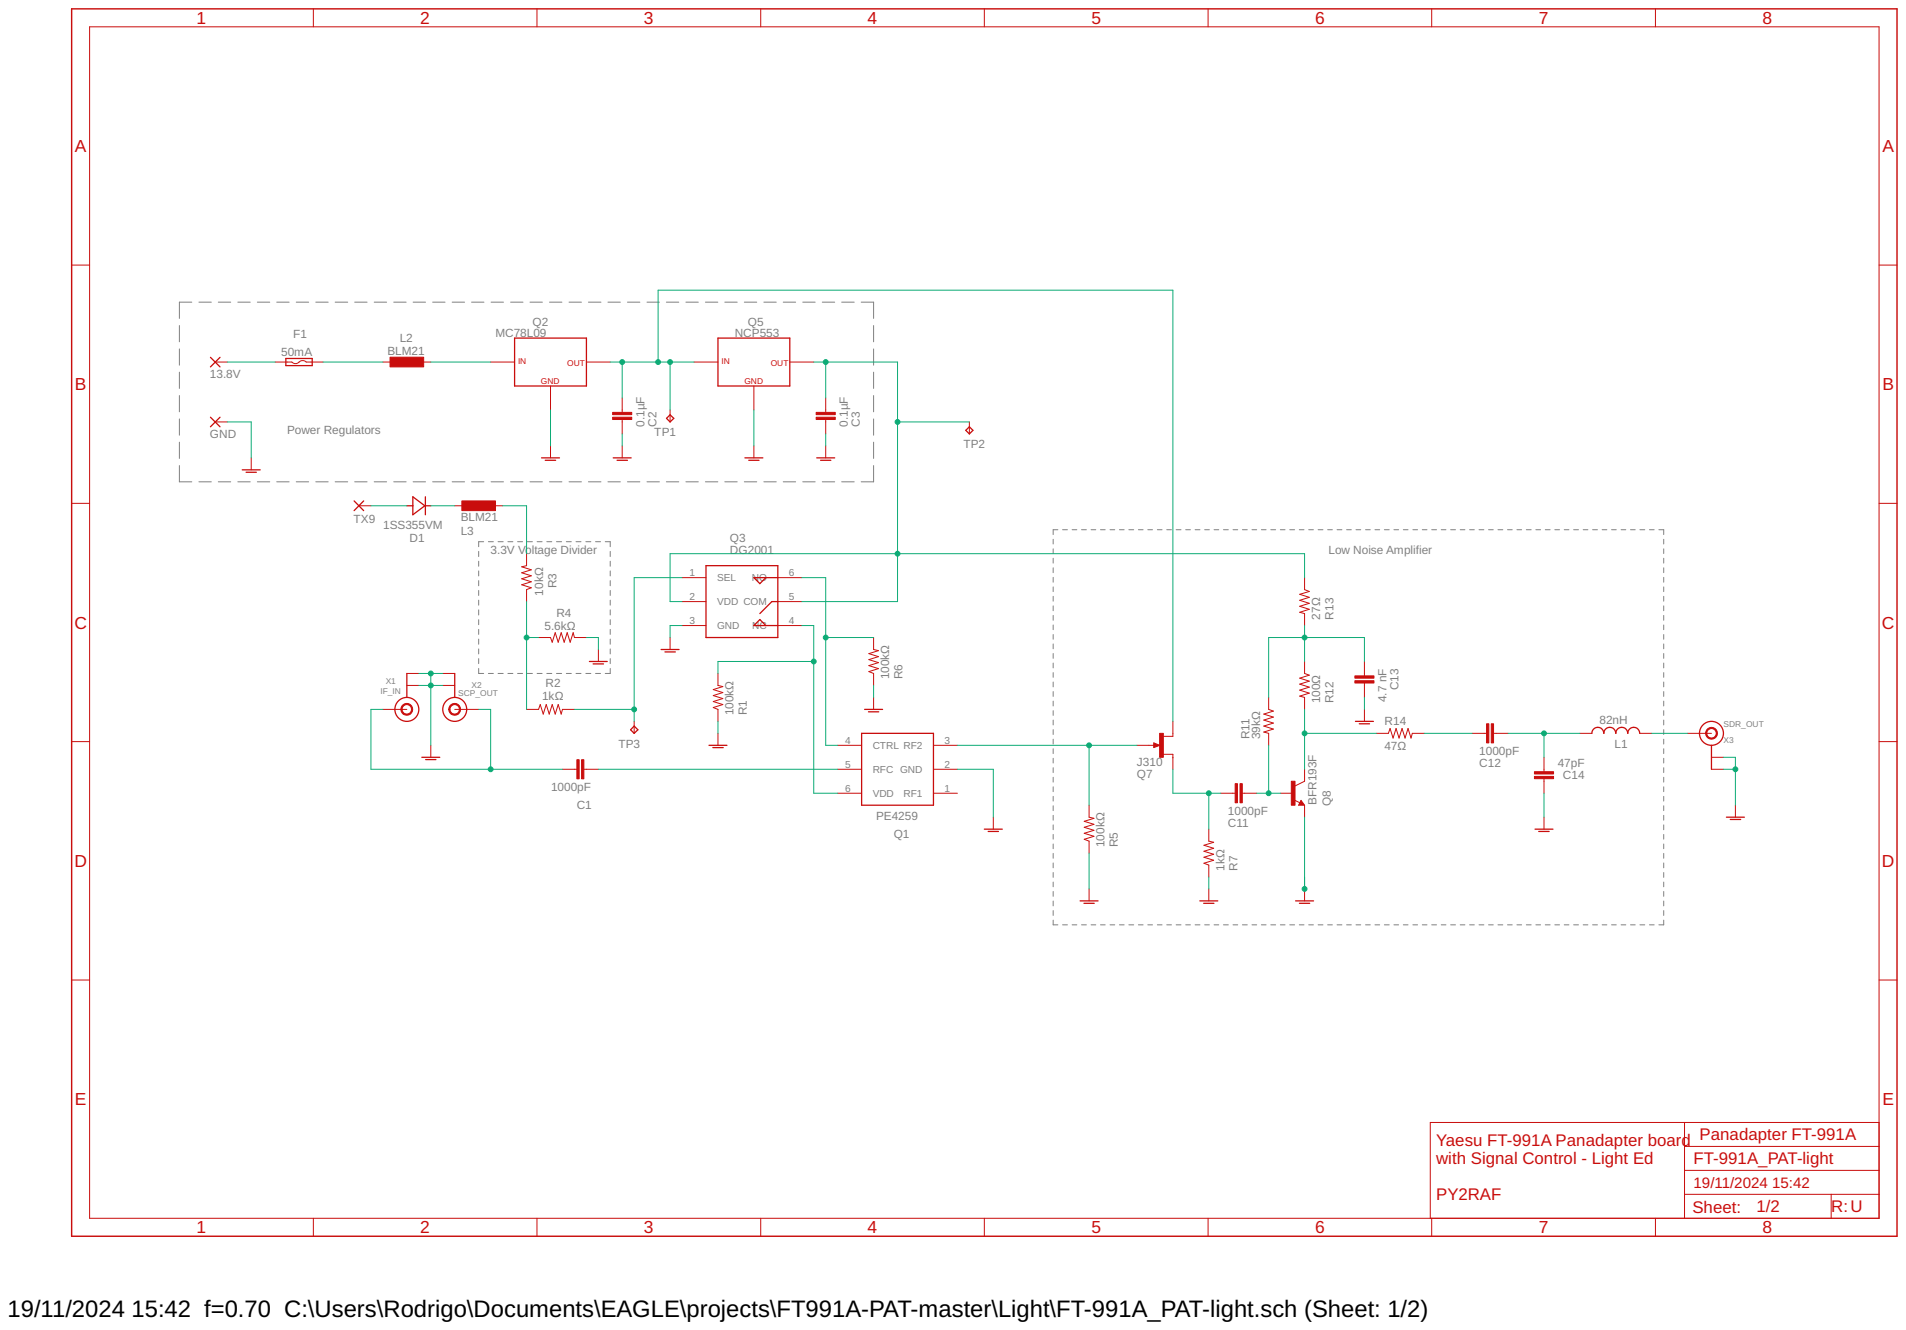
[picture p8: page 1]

Yaesu FT-991A Panadapter board with Signal Control - Light Ed

19/11/2024 15:42 f=0.70 C:\Users\Rodrigo\Documents\EAGLE\projects\FT991A-PAT-master\Light\FT-991A_PAT-light.sch (Sheet: 1/2)

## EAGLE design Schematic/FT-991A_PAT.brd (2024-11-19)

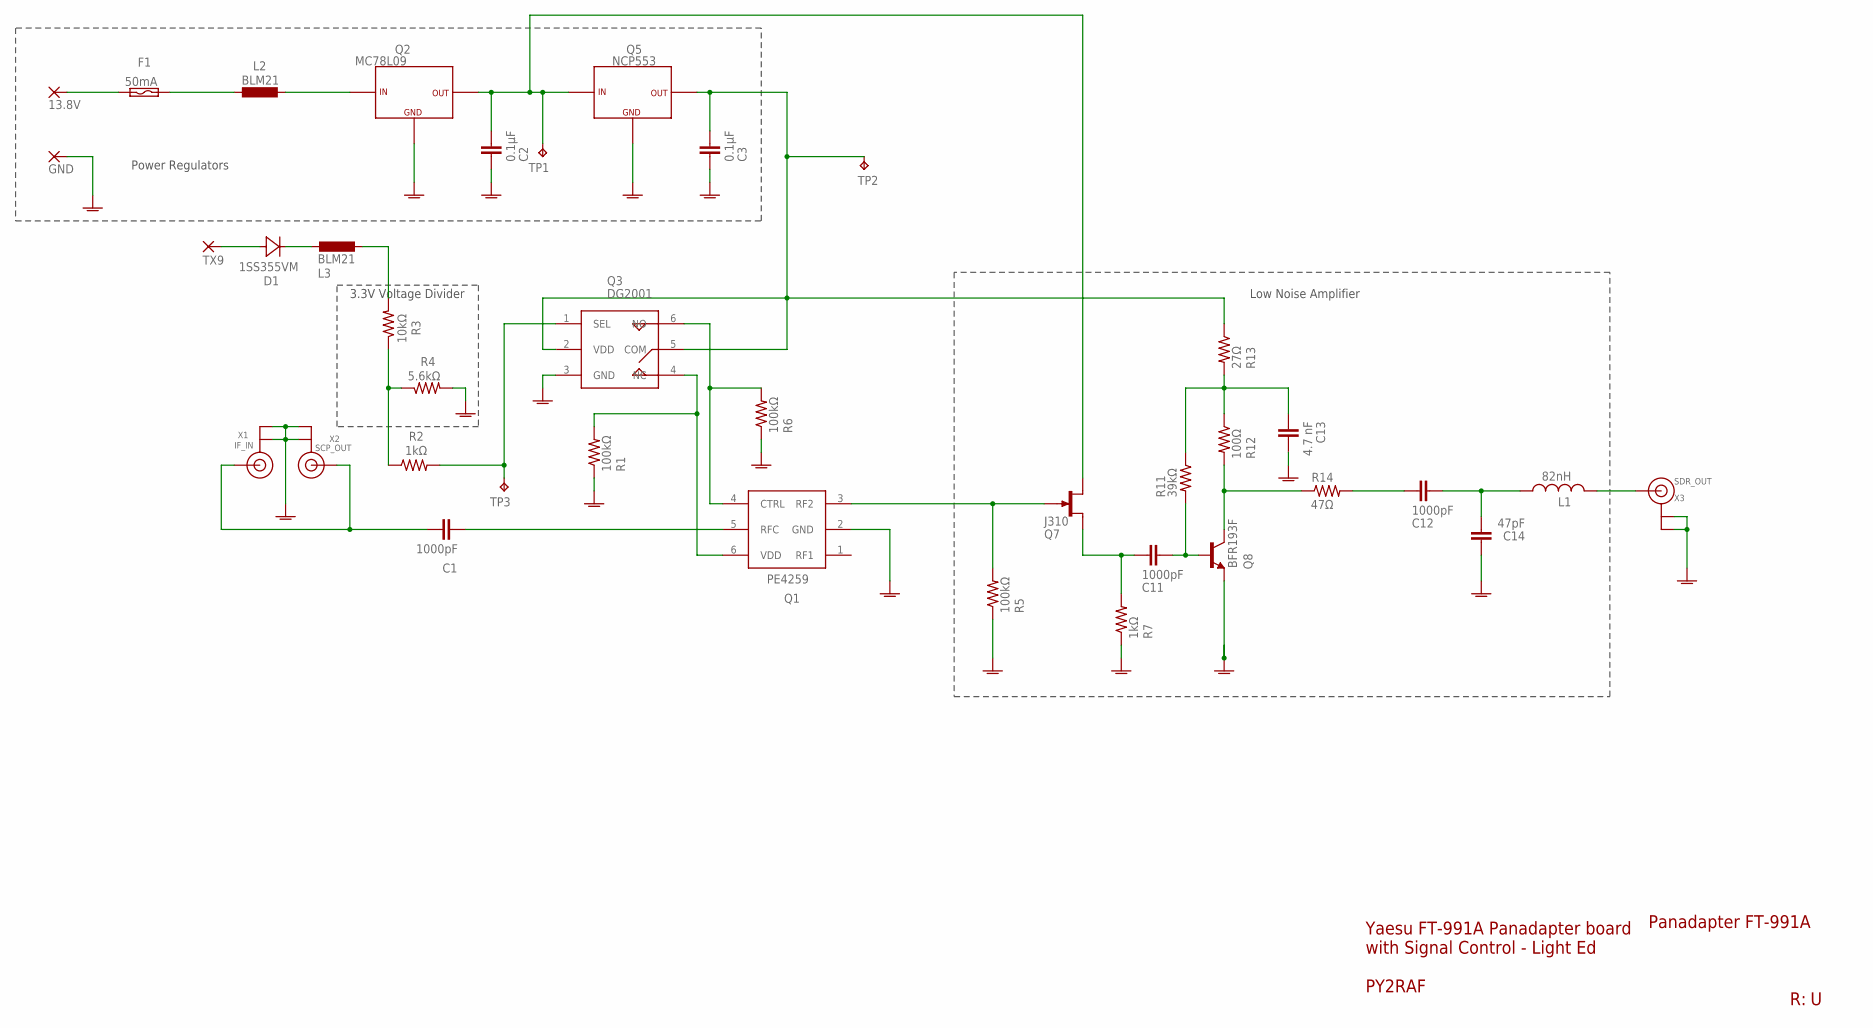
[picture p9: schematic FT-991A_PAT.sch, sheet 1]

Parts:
13.8V: 13.8V; SMD1,27-2,54
C1, C11, C12: 1000pF; 0805
C2, C3: 0.1µF; 1206
C13: 4.7 nF; 1206
C14: 47pF; 0805
D1: 1SS355VM; SOD-323
F1: 50mA; FUSE-1206
GND: GND; SMD1,27-2,54
L1: 82nH; 0805
L2, L3: BLM21; 0805
PAD3: TX9; SMD1,27-2,54
Q1: PE4259; SC-70
Q2: MC78L09; SOIC8
Q3: DG2001; SOT23-6
Q5: NCP553; SC-82AB
Q7: J310; SOT23-3
Q8: BFR193F; TSFP-3
R1, R5, R6: 100kΩ; 1206
R2, R7: 1kΩ; 1206
R3: 10kΩ; 1206
R4: 5.6kΩ; 1206
R11: 39kΩ; 1206
R12: 100Ω; 1206
R13: 27Ω; 1206
R14: 47Ω; 1206
TP1: 9V; B1,27
TP2, TP3: 3V; B1,27
X1: IF_IN; U.FL
X2: SCP_OUT; U.FL
X3: SDR_OUT; U.FL

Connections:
3V: C3.1, Q3.2 (VDD), Q3.5 (COM), Q5.3 (OUT), R13.1, TP2.TP
9V: C2.1, Q2.1 (OUT), Q5.2 (IN), Q7.2 (S), TP1.TP
FB-3V: C13.1, R11.1, R12.1, R13.2
FINAL: L1.P$2 (2), X3.3 (SIGNAL)
GNDA: C2.2, C3.2, C13.2, C14.P$1 (1), GND.1, Q1.2 (GND), Q2.2 (GN), Q2.3 (GN), Q2.6 (GN), Q2.7 (GN), Q3.3 (GND), Q5.1 (GN), Q8.2 (E), R1.1, R4.2, R5.1, R6.1, R7.1, X1.1 (GND), X1.2 (GND), X2.1 (GND), X2.2 (GND), X3.1 (GND), X3.2 (GND)
IFTAP: C1.P$2 (2), Q1.5 (RFC)
unnamed: Q3.1 (SEL), R2.2, TP3.TP
unnamed: R2.1, R3.1, R4.1
unnamed: D1.A, PAD3.1
unnamed: L3.P$2 (2), R3.2
unnamed: L2.P$1 (1), Q2.8 (IN)
unnamed: 13.8V.1, F1.1
unnamed: F1.2, L2.P$2 (2)
unnamed: D1.C, L3.P$1 (1)
NC: Q1.6 (VDD), Q3.4 (NC), R1.2
NO: Q1.4 (CTRL), Q3.6 (NO), R6.2
RAWIN: C1.P$1 (1), X1.3 (SIGNAL), X2.3 (SIGNAL)
ST1IN: Q1.3 (RF2), Q7.3 (G), R5.2
ST1M1: C11.P$1 (1), Q7.1 (D), R7.2
ST2IN: C11.P$2 (2), Q8.1 (B), R11.2
ST2M1: C12.P$1 (1), R14.2
ST2M2: C12.P$2 (2), C14.P$2 (2), L1.P$1 (1)
ST2OUT: Q8.3 (C), R12.2, R14.1

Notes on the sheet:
Panadapter FT-991A
PY2RAF
Yaesu FT-991A Panadapter board with Signal Control - Light Ed
3.3V Voltage Divider
Low Noise Amplifier
Power Regulators

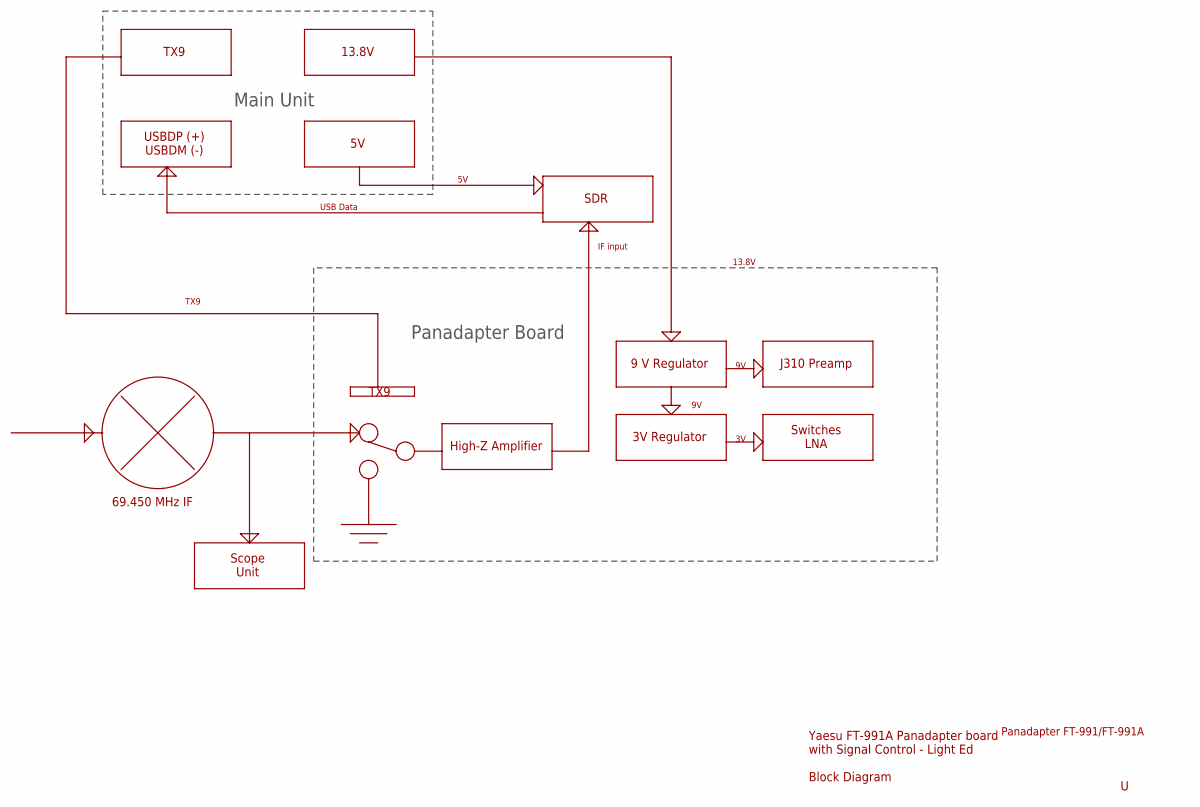
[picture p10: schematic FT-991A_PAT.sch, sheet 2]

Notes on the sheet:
Scope Unit
TX9
69.450 MHz IF
SDR
13.8V
Main Unit
Panadapter Board
IF input
Panadapter FT-991/FT-991A
Yaesu FT-991A Panadapter board with Signal Control - Light Ed Block Diagram
USBDP (+) USBDM (-)
USB Data
High-Z Amplifier
9 V Regulator
3V Regulator
J310 Preamp
Switches LNA

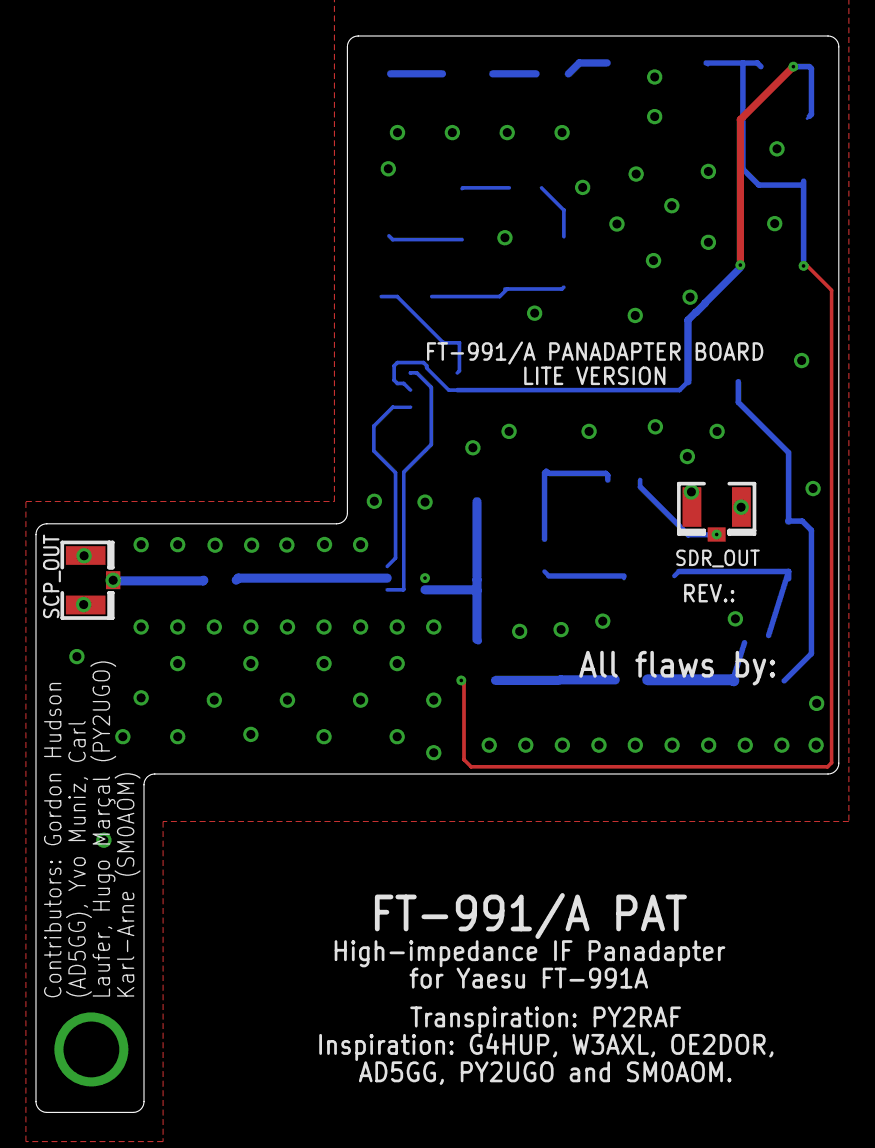
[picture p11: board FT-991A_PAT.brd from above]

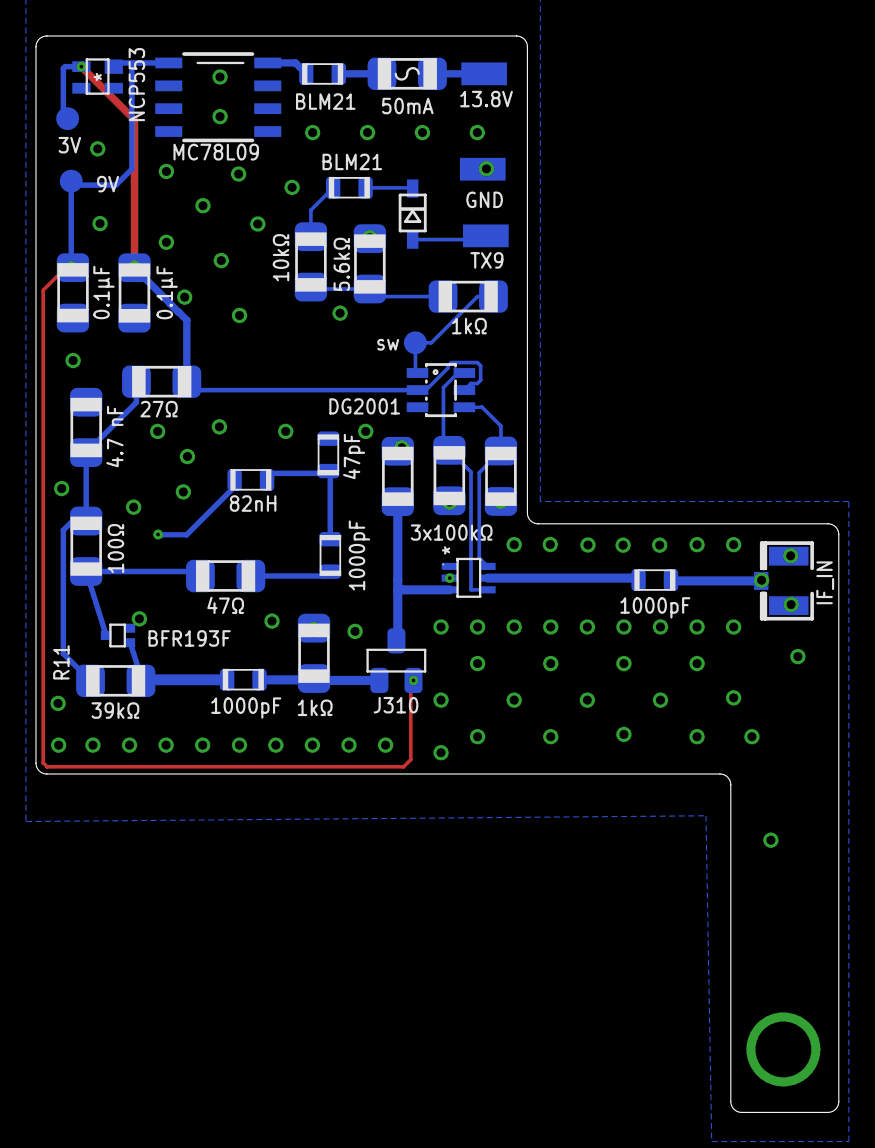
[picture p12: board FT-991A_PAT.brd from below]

Board: 2 copper layers, 44.6 x 59.8 mm, 38 parts (36 on the bottom side), 23 nets.

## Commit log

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2019-03-25 Revision D
    - Reusing OE2DOR design
    - Added a AND gate and a switch to be able to control the IF traffic
    to the dongle
    [FT-991A_PAT.sch]
2019-03-25 Revision E
    - Now sports a RF switch (PE4259) instead of a regular Analog switch
    (was: SN74LVC1G66);
    * Also contains its resistors as per reference design;
    - Changed voltage from 5V to 3.3V to Switch and AND port;
    - SDR output will be grounded by default when switch is in default state
    (RF 2 port) port
    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
    [FT-991A_PAT.brd, FT-991A_PAT.sch]
2019-03-27 Revision F
    * Added 1 nF capacitors in RF lines in PE4529 (except RF2, goes with a
    470 pF to GND)
    * Got rid of the VCC via which was crossing the RF line (argh)
    * Finally got the courage to change a bit the board layout and escape
    from the thin strip that I was working previously.
    * And another THANK YOU to Gordon AD5GG for his invaluable feedback and
    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
    [FT-991A_PAT.brd, FT-991A_PAT.sch]
2019-03-27 New files, correction, better schematic layout
    Still in Revision F:
    * Fixed C14 values (it is 4.7 nF and not 470 pF)
    * Cleaner and unified board layout
    * Identified properly Q1 (it is a J310)
    * A few tweaks and spam in board silk screen
    * Added project's PDF and board's PNG images
    ... And that's all, folks! \o
    [FT-991A_PAT.brd, FT-991A_PAT.sch]
2019-03-27 Reorganized directory structure
    * Moved Schematics to Schematic folder
    * Moved parts/BOM to Design folder
    * Updated README file to reflect the changes
    [FT-991A_PAT.brd, FT-991A_PAT.sch]
2019-03-28 Revision G
    Removed a lingering DC blocking 1nF capacitor after RF switch
    [FT-991A_PAT.brd, FT-991A_PAT.sch]
2019-03-28 Revision G.1 - Added choke in DC IN lines
    As per Gordon Hudson (AD5GG):
    "I'd also place a BLM18 type ferrite (BLM18AG102SN1) on your board right
    where the 5V enters your circuit to choke off any noise from the
    RTL-SDR."
    Gordon, remember that I don't have the Soldering Overlord that you have
    ;-P
    The BLM18AG102SN1 is not down to my soldering abilities, so I picked a
    BLM21AG102SN1 - Same ratings, larger footprint.
    [FT-991A_PAT.brd, FT-991A_PAT.sch]
2019-03-29 Revision H
    * Revised routes in Cheb Filter - Made the tracks fatter and straighter
    * Repositioned Q2 for better signal routing
    * Better unit spelling in silk screen for resistors
    * Flipped IF/SCP ports
    * A few routing changes.
    [FT-991A_PAT.brd, FT-991A_PAT.sch]
2019-03-30 Updated Parts
    * New Parts file
    * Added a Digikey-formatted BOM
    * Schematic with a few part renames, nothing noteworthy
    [FT-991A_PAT.brd, FT-991A_PAT.sch]
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2019-04-08 Revision I
    Added:
    * RTL-SDR USB port
    * U.FL jumper cords in BOM
    * 3 power regulators in the board
    Changed:
    * Power supply: Now uses a single external 13.8V voltage source
    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
    [FT-991A_PAT.brd, FT-991A_PAT.sch, bom-ft991a-panadapter.csv]
2019-05-18 evision J
    - Board Revision J:
    * Changed SCPON signal to RX9
    - Added a Voltage Divider
    * Added a few vias in large ground pads for voltage regulators
    * Moved USB port a bit back in PCB
    - Changed a few components in BOM (mostly wrong footprints)
    - Updated Readme
    - Added Gerber files
    [FT-991A_PAT.brd, FT-991A_PAT.sch, bom-ft991a-panadapter.csv]
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2019-05-20 Revision K
    * Changed footprints: BOM specifies 1206, project had 0805
    - Unified everything Resistors and Capacitors in 1206
    - Inductors are 0805
    * A few routing enhancements
    * Recalculated the component indexes
    * Updated BOM to reflect the new component index
    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
    [FT-991A_PAT.brd, FT-991A_PAT.sch, bom-ft991a-panadapter.csv]
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2019-05-24 EXPERIMENTAL: Revision L
    Long shot. In this revision:
    * Added the ability to bypass entirely the amplifier and filters
    - Selectable by RF switch (default: off)
    * Added a 3-pole Chebyshev Band-pass Filter centered at 69.450 MHz, 3
    MHz wide
    - Selectable by RF switch (default: off)
    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
    [FT-991A_PAT.brd, FT-991A_PAT.sch, bom-ft991a-panadapter.csv]
2019-05-30 Revision M
    In this revision:
    * Got rid of the USB receptacle - Too much space in a tight radio
    * Moved all GPIO pads to the upper board side
    * Added a few missing Pin 1 references
    * Renamed voltage regulators to somewhat shorter name
    * Small re-routing - 9V regulator was entangled with capacitor
    [FT-991A_PAT.brd, FT-991A_PAT.sch, bom-ft991a-panadapter.csv]
2019-05-31 Removed USB jack and U.FL to SMA cables
    Not needed, won't fit in the project.
    [bom-ft991a-panadapter.csv]
2019-06-22 Revision N - No USB
    A truckload of changes. Namely:
    * Removed the 5V regulator
    * Removed the USB provisions
    * Removed the G4HUP LPF. Reasoning: Found it of no use, since it cuts
    * the signal 24 MHz above the IF center frequency. The selectable BPF
    * suits better.
    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
    [FT-991A_PAT.brd, FT-991A_PAT.sch, bom-ft991-panadapter.csv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]
2019-06-22 Corrected BOM url
2019-08-21 A few corrections in content
    Removed a few stale images
    Updated BOM
    Added a better BPF chart
    A few enhancements in Schematic/Block Diagram
    [FT-991A_PAT.sch, bom-ft991-panadapter.csv]
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2019-09-04 Starting Revision O Redesign
    Still preliminary, a lot more work to do.
    [FT-991A_PAT.brd, FT-991A_PAT.sch]
2019-10-05 Revision O: Moving toward golden
    Components placed, new BPF design (tips hat to Karl-Anne SM0AOM)
    Major board reorganization
    [FT-991A_PAT.brd, FT-991A_PAT.sch]
2019-10-07 More Rev. O Advancements
    Reviewed Ground Plane
    Added (lots of) ground plane vias
    Renumbered parts
    Ran DRC and fixed a lot of airwires
    A few component positioning hacks
    Updated the Project Overview Block Diagram sheet
    Updated credits
    Removed obsolete amplifier LTSPICE file
    [FT-991A_PAT.brd, FT-991A_PAT.sch]
2019-10-12 Revision O: A few minor (toward GA) changes
    Minor board labelling enhancements
    Updated BOM, Gerber and Readme
    [FT-991A_PAT.brd, FT-991A_PAT.sch, bom-ft991-panadapter.csv]
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2019-11-03 Board: Eagle image while board doesn't get assembled.
2019-11-12 Fuse: Corrected fuse value to 50 mA
    [FT-991A_PAT.brd, FT-991A_PAT.sch]
2019-11-24 Light Edition: Initial commit
    Presenting... Light Edition!
    * A slimmer BoM
    * ... $ SAVINGS!
    * Less insertion loss, moar GAIN
    * Less building time
    * Essentials for the win.
    [FT-991A_PAT.brd, FT-991A_PAT.sch, bom-ft991-panadapter.csv]
2019-11-24 Corrected Block Diagram
    Removed a GPIO 32 from block diagram - Just not used in this revision.
    [FT-991A_PAT.sch]
2019-11-25 Light Ed.: Small PCB Correction
    * Repositioned a capacitor and straightened a power line
    * Also cleaned a few PCB DRC Warnings
    [FT-991A_PAT.brd]
2019-11-25 Lite Ed.: Board rerouting, removed C12
    C12 was lingering from the previous RF Switch, got rid of it
    Small routing changes
    [FT-991A_PAT.brd, FT-991A_PAT.sch, bom-ft991-panadapter.csv]
2020-06-20 Fixed capacitor unit
    [bom-ft991-panadapter.csv]
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2020-06-28 Starring: Revision P
    * Repositioned the SDR Out port to right above the DC block cap
    * Changed RF switch layout - now IF input uses the RF switch's `RFC`
    port instead of RF2 - It seems that the PE4259's `RF{N}` port gets in
    a grounded state instead of just reflecting out the data when not
    selected / active
    * Got rid of the "Grounding" in RF1 port; that's not necessary
    because... Above
    * Few text corrections
    [FT-991A_PAT.brd, FT-991A_PAT.sch]
2020-06-28 Removed 4.7 nF capacitor (C2) used in RF Ground
    This capacitor no longer exists, due to PE4259 flipping.
    [bom-ft991-panadapter.csv]
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2020-06-28 Reorganized BOM, removed BPF design file
    No need for the BPF file - this verson has no BPF.
    Reorganized the BOM - just meaningful component placement.
    [bom-ft991-panadapter.csv]
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2020-06-28 Fixed board images
2020-06-28 Board: Added test pads
    Added test pads for 9V, 3V and RF Switch.
    [FT-991A_PAT.brd, FT-991A_PAT.sch]
2020-07-01 Ground plane and board design change
    Moved a power line to the board border instead traveling by the middle
    of the board, essentially (unnecessarily) splitting in two the board
    ground planes.
    New gerber.
    [FT-991A_PAT.brd]
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2020-08-10 Preparing: Revision Q
    * Better Silk-Screen Pin 1 markings for Power regulators
    * Larger footprint for 2SC5086
    * Moving 0.1µF transistor caps away from RF section
    * Lots of re-routing
    * Changing 1 nF caps to Low ESL type and 0805 footprint for better RF
    performance
    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
    [FT-991A_PAT.brd, FT-991A_PAT.sch]
2020-08-11 Fixed Bill of Materials
    Was broken when merged.
    [bom-ft991-panadapter.csv]
2020-08-11 BOM: Fixed bill of materials
    Was broken when merging
    [bom-ft991-panadapter.csv]
2020-08-11 Fixed BOM; this revision still uses 1206 caps
    and previous commit specified an 0805 cap - which will be used in Rev Q
    onwards
    [bom-ft991-panadapter.csv]
2020-10-10 Minor routing hacks
    - Replaced J310 JFET
    * Taking full advantage of its Source and Drain interchangeability
    * Avoiding some signal track xing
    - And more routing changes.
    [FT-991A_PAT.brd, FT-991A_PAT.sch]
2020-10-11 Changed J310 to a new active variant
    Resolves #13 - Component went to obsolete state.
    Thanks to @wgxdz for pointing.
    [bom-ft991-panadapter.csv]
2020-10-11 Changed J310 to an active variant
    Reported in #13 - Component went to obsolete state.
    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
    [bom-ft991-panadapter.csv]
2020-10-21 Rev. Q more enhancements
    - Changed two resistors in Amplifier chain in order to get some more
    gain - See Issue 14
    - Updated BOM in order to reflect this change
    - Added a ground pad, that's useful when troubleshooting and the lack
    of it bit my butt a number of times
    [FT-991A_PAT.brd, FT-991A_PAT.sch, bom-ft991-panadapter.csv]
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2022-01-28 Christening Rev. R
    * New PDF files
    * Voltage regulator re-routing
    * Larger NCP533 and Diode pads
    * Fixed some BOM errors
    * Removed some old files
    * Added Eagle Library file
    * Fixed Readme links
    [FT-991A_PAT.brd, FT-991A_PAT.sch, bom-ft991-panadapter.csv]
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2022-03-16 BOM: Changed Ferrite Bead part
    Replaced the Murata choke with a Bourns one, due to Murata unavailability.
    [bom-ft991-panadapter.csv]
2022-04-12 Announcing: Rev. S
    * Replaced 2SC5086 with BFR193F amplifier, since 2SC5086 is now EOL
    * Added a RF choke (L1) to avoid signal feedback propagating in 3V line
    [FT-991A_PAT.brd, FT-991A_PAT.sch, bom-ft991-panadapter.csv]
2022-05-23 Fixed part number for 100K R
    [bom-ft991-panadapter.csv]
2022-07-19 Rev. S: New RF switch actuation
    * New RF switch design - now uses an analog switch to flip the RF switch.
    While this added new parts (1 switch and two resistors) and extra
    complexity, this actuation format is industry-standard and allows
    for substitutes of PE4259 (which is unobtanium as of now).
    * New component in library (NLAS4599)
    [FT-991A_PAT.brd, FT-991A_PAT.sch, bom-ft991-panadapter.csv]
2022-07-26 Minor board fixes
    * Ran board through DRC and added some extra clearances
    * Analog switch label silkscreen was missing
    [FT-991A_PAT.brd]
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2023-11-16 Revision S improvements
    - Very minor changes on board design around the power regulator,
    allowing for extra clearance for part description
    - Replaced the EOLed OnSemi switch with an active Vishay one
    - Updated the overall board block diagram
    [FT-991A_PAT.brd, FT-991A_PAT.sch]
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2023-11-16 Update bom-ft991-panadapter.csv
    Fixed 100k resistor PN
    Changed RF switch to a compatible part (PE42421)
    Changed J310 part to an available variant
    [bom-ft991-panadapter.csv]
2024-05-28 Featuring: Revision T
    * Fixed a gross flaw in Revision S: The RF switch was flipped out /o\ Resolves #25
    * Updated BOM, renamed some capacitors and the matching network components are labeled as {C,R}1x
    * There are more gain to be obtained from BFR193. Added a bias and matching network design from [Infineon's AN-1806](https://www.infineon.com/dgdl/Infineon-Design_Guide_for_low_noise_TR_in_FM_radio_FE-ApplicationNotes-v01_00-EN.pdf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). While the matching network isn't suitable for BFR193, the footprints will be good enough to test other components and values. Capacitors are 0805, Resistors are 1206.
    * This revision is planned to be a testbed for a proper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
    [FT-991A_PAT.brd, FT-991A_PAT.sch, bom-ft991-panadapter.csv]
2024-11-19 Announcing: Revision U
    Featuring:
    * A properly matched BFR193F transistor, yielding 7 dB of gain,
    surpassing 2SC5086
    * Larger pads for BFR193F
    * Few routing improvements, larger wires
    * Removed a via near the 3V regulator, didnt help a lot and was
    a short circuit risk.
    [FT-991A_PAT.brd, FT-991A_PAT.sch, bom-ft991-panadapter.csv]
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2024-11-20 BOM: Wrong value for resistor
    [bom-ft991-panadapter.csv]
2024-12-10 Update bom-ft991-panadapter.csv
    Fixed diode DigiKey PN
    [bom-ft991-panadapter.csv]
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

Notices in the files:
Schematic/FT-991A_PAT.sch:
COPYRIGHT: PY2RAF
